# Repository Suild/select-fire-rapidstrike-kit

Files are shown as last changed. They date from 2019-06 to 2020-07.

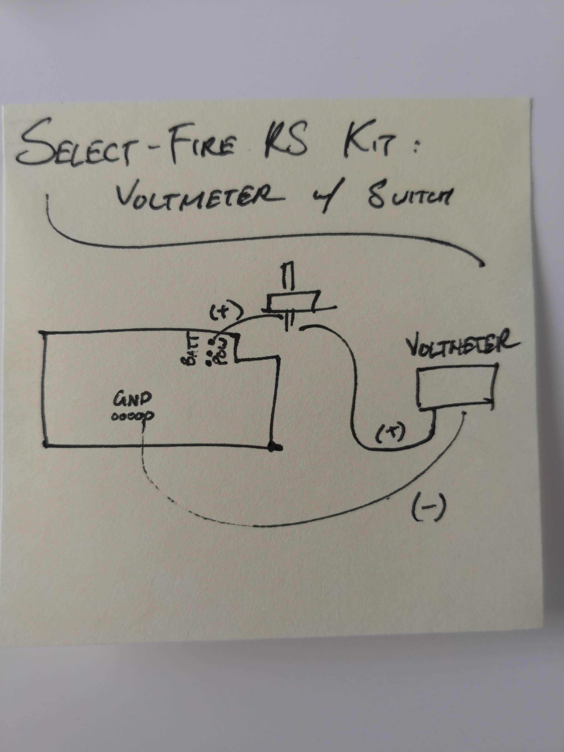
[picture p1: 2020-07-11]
Wiring Diagrams/Voltmeter with Kill Switch.jpg

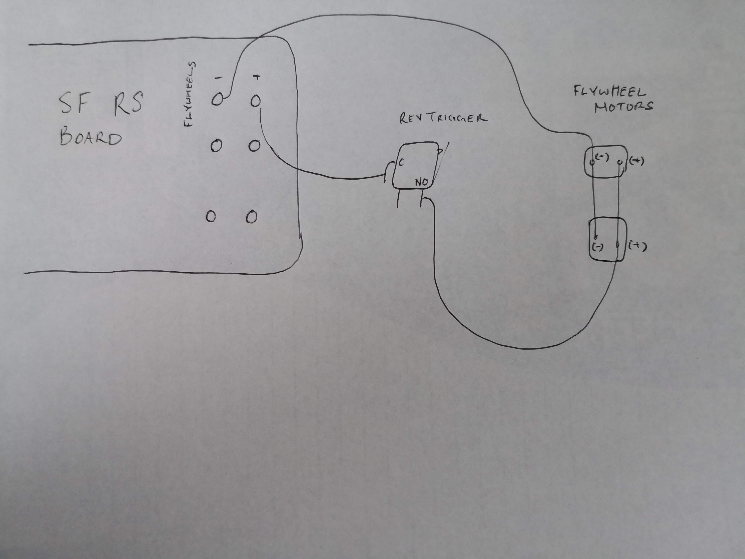
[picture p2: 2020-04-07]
Wiring Diagrams/Flywheel Motors with Microswitch.jpg

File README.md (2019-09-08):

# select-fire-rapidstrike-kit
Schematics, board files, and firmware for every variant of the Select-fire Rapidstrike Kit.



Buy Link: https://suild.com/shop/4

Grants reliable select-fire control to your Rapidstrike with optional rate of fire control using a knob. Like every other kit, this one is super simple to install and requires no soldering directly onto the board to get everything up and runing in under a minute, even easier than a regular RS mod!

Built-in pusher return and solenoid support makes this kit easily adaptable to any custom 3D-printed blaster. A powerful voltage regulator buck converter, on-board Arduino Nano, and breakout of power rails make this ideal for tinkerers and Makers who want to bring this kit one step farther. And everything is open-source.

I hope you find value in this. I personally learned a lot from open-source projects. I've included a PDF for every schematic and images of the top and bottom for every board so you can view them on mobile and without installing Eagle CAD.

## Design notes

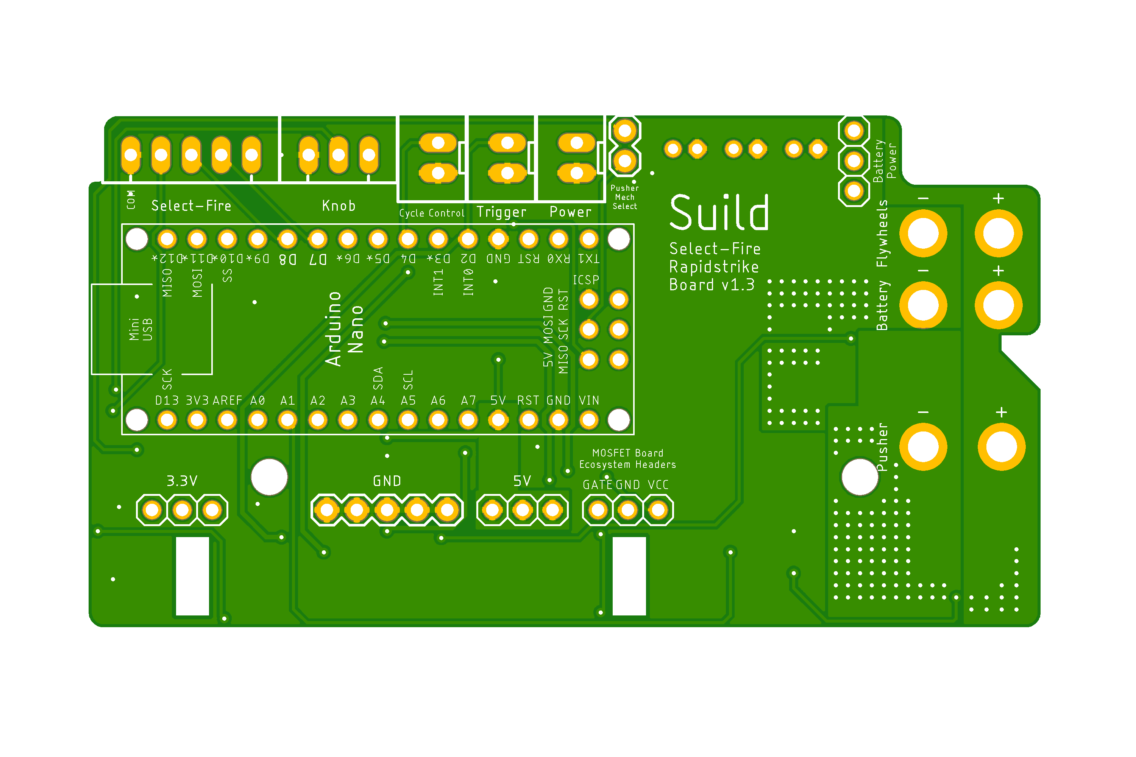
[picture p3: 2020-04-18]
v1.3/Hardware/PCB Top.png

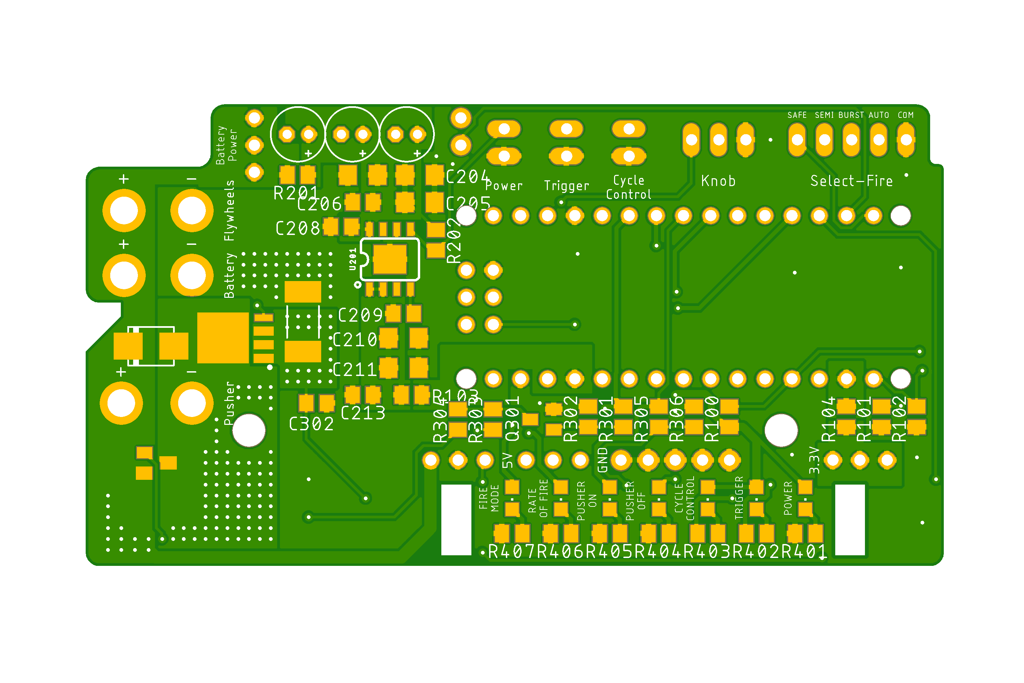
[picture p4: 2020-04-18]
v1.3/Hardware/PCB Bottom.png

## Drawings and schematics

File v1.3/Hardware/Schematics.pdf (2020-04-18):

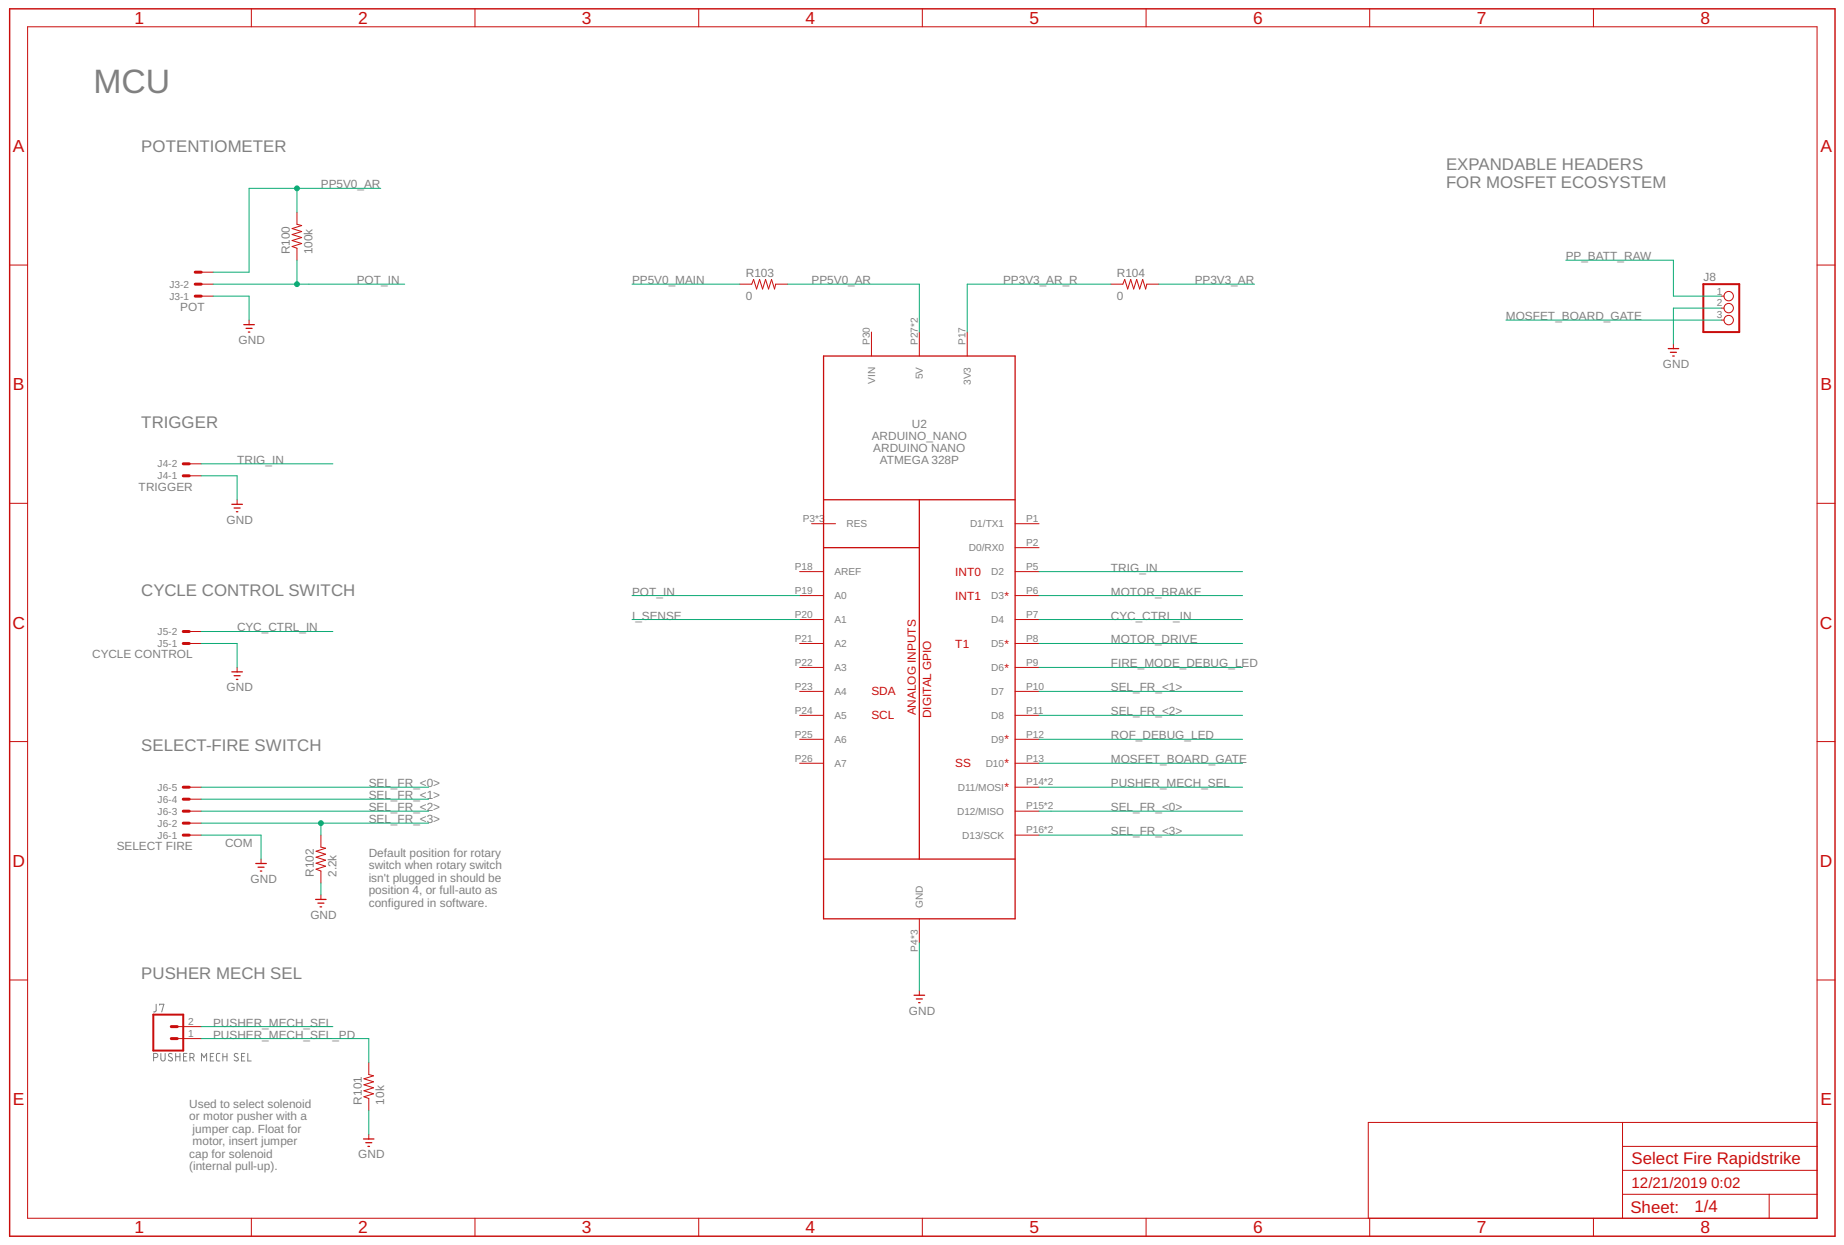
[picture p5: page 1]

ANALOG INPUTS DIGITAL GPIO

Default position for rotary
switch when rotary switch
isn't plugged in should be
position 4, or full-auto as
configured in software.

Used to select solenoid
or motor pusher with a
jumper cap. Float for motor, insert jumper cap for solenoid

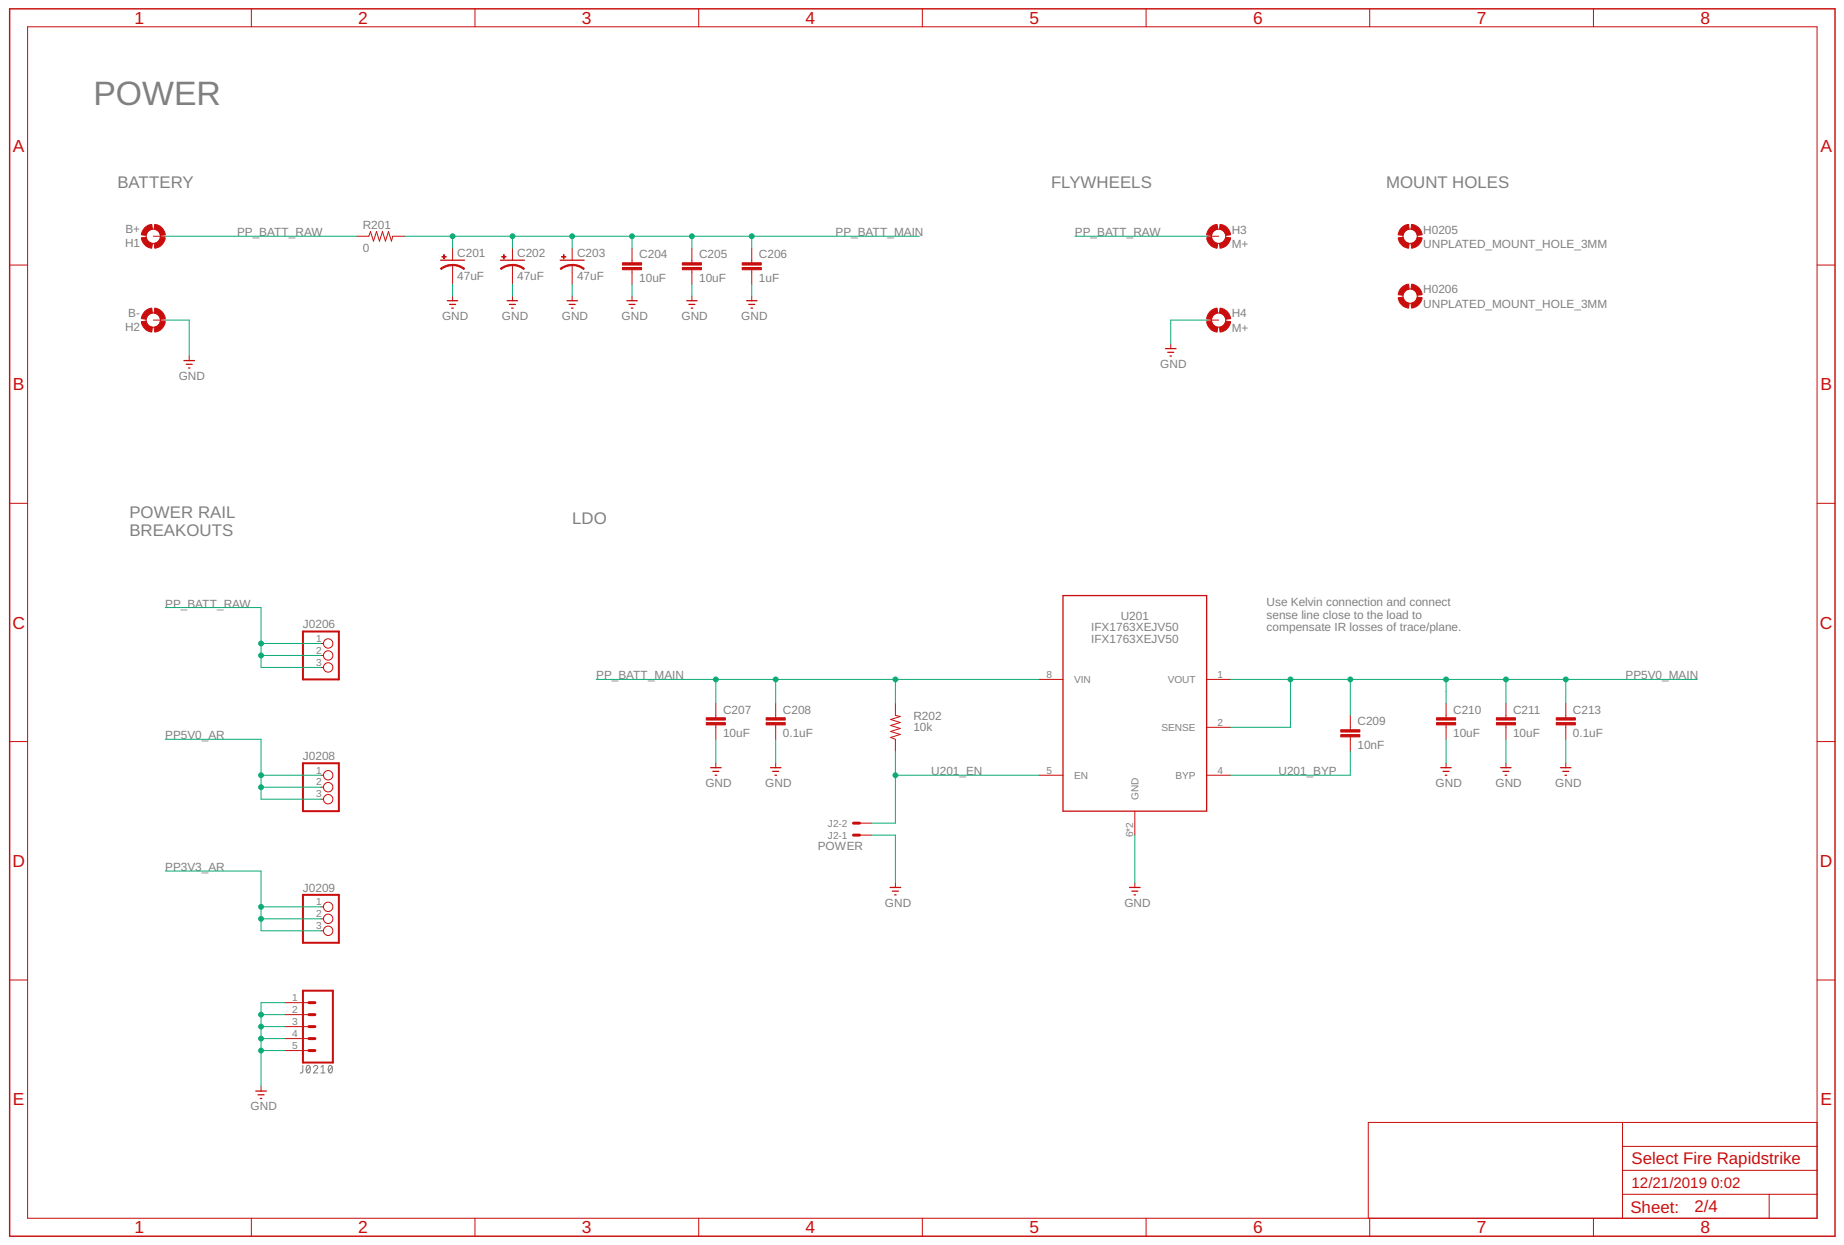
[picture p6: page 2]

Use Kelvin connection and connect sense line close to the load to

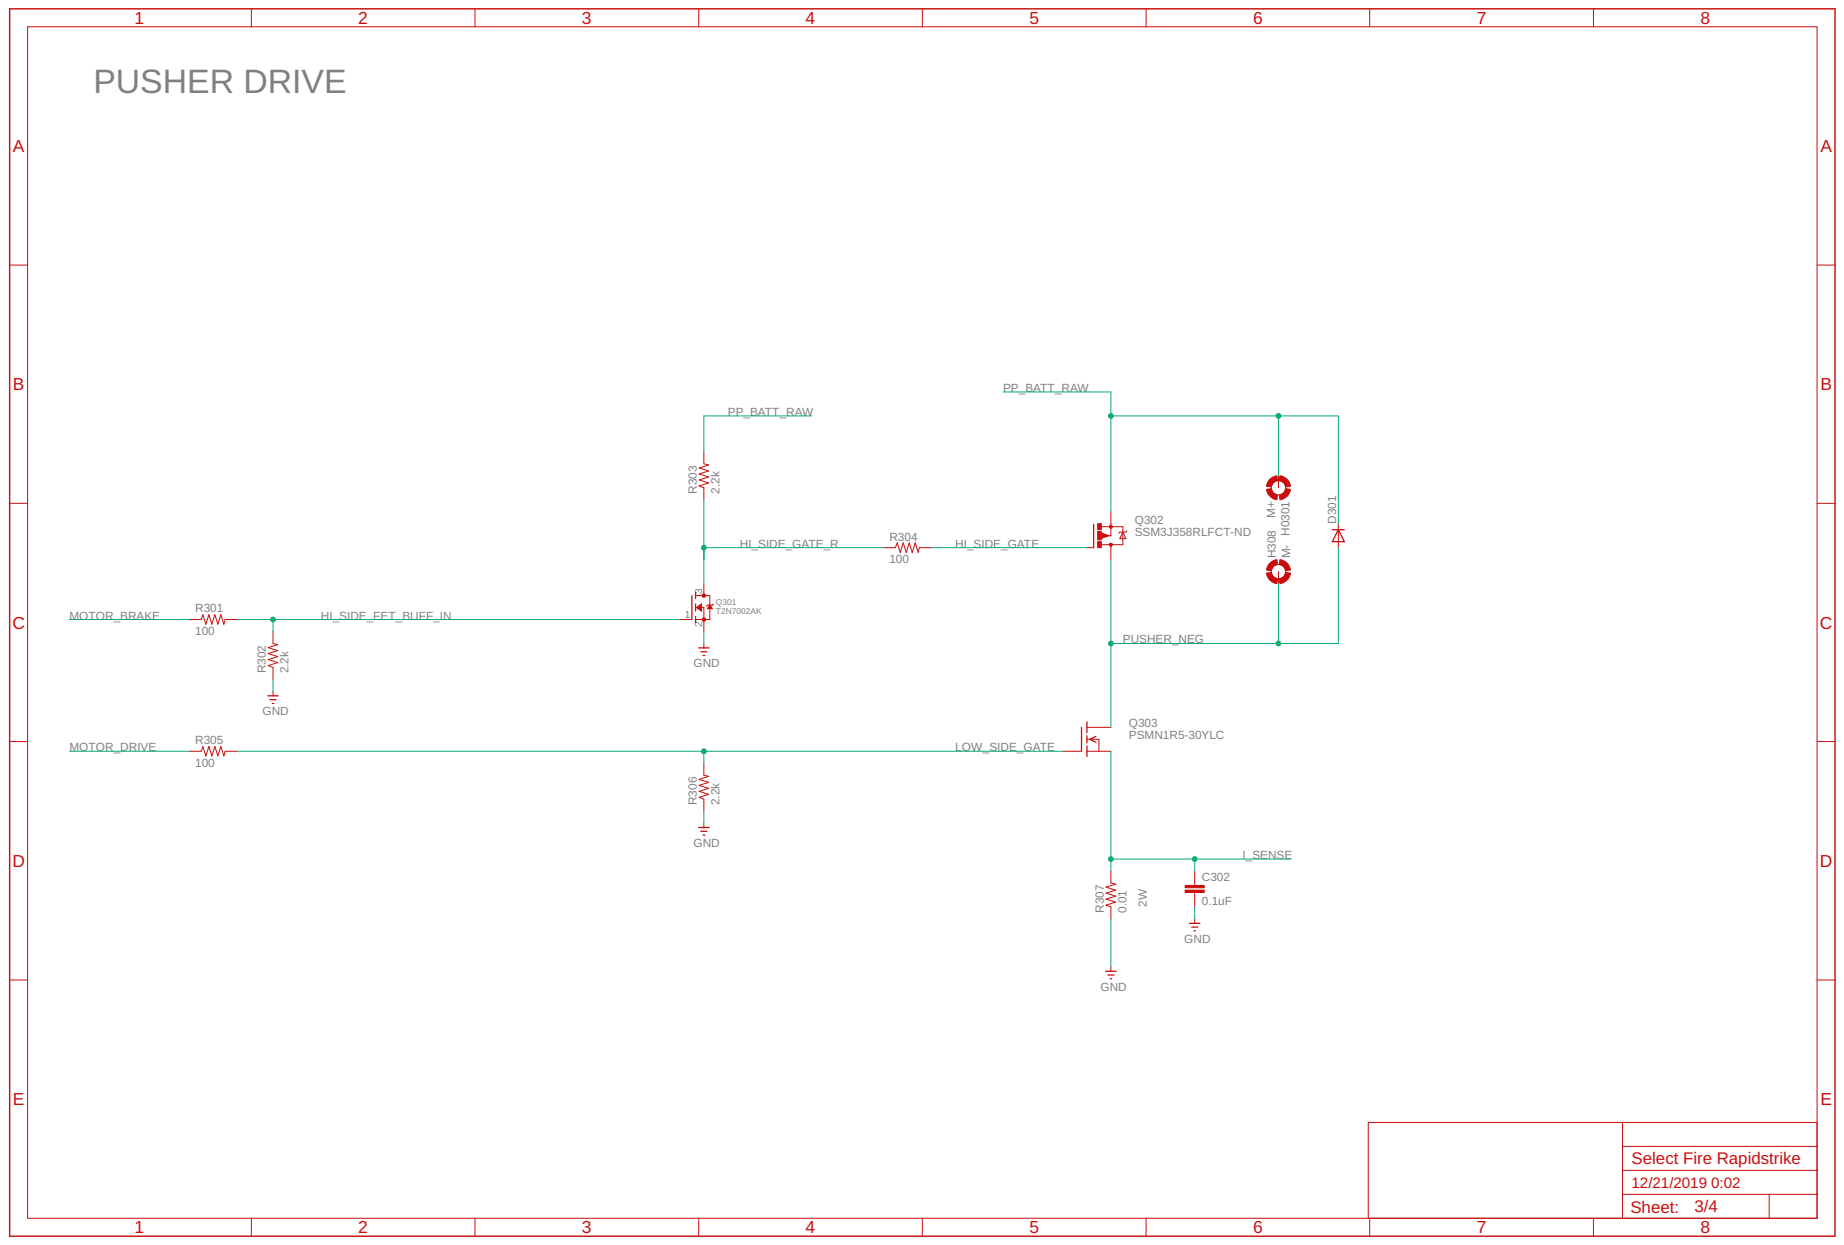
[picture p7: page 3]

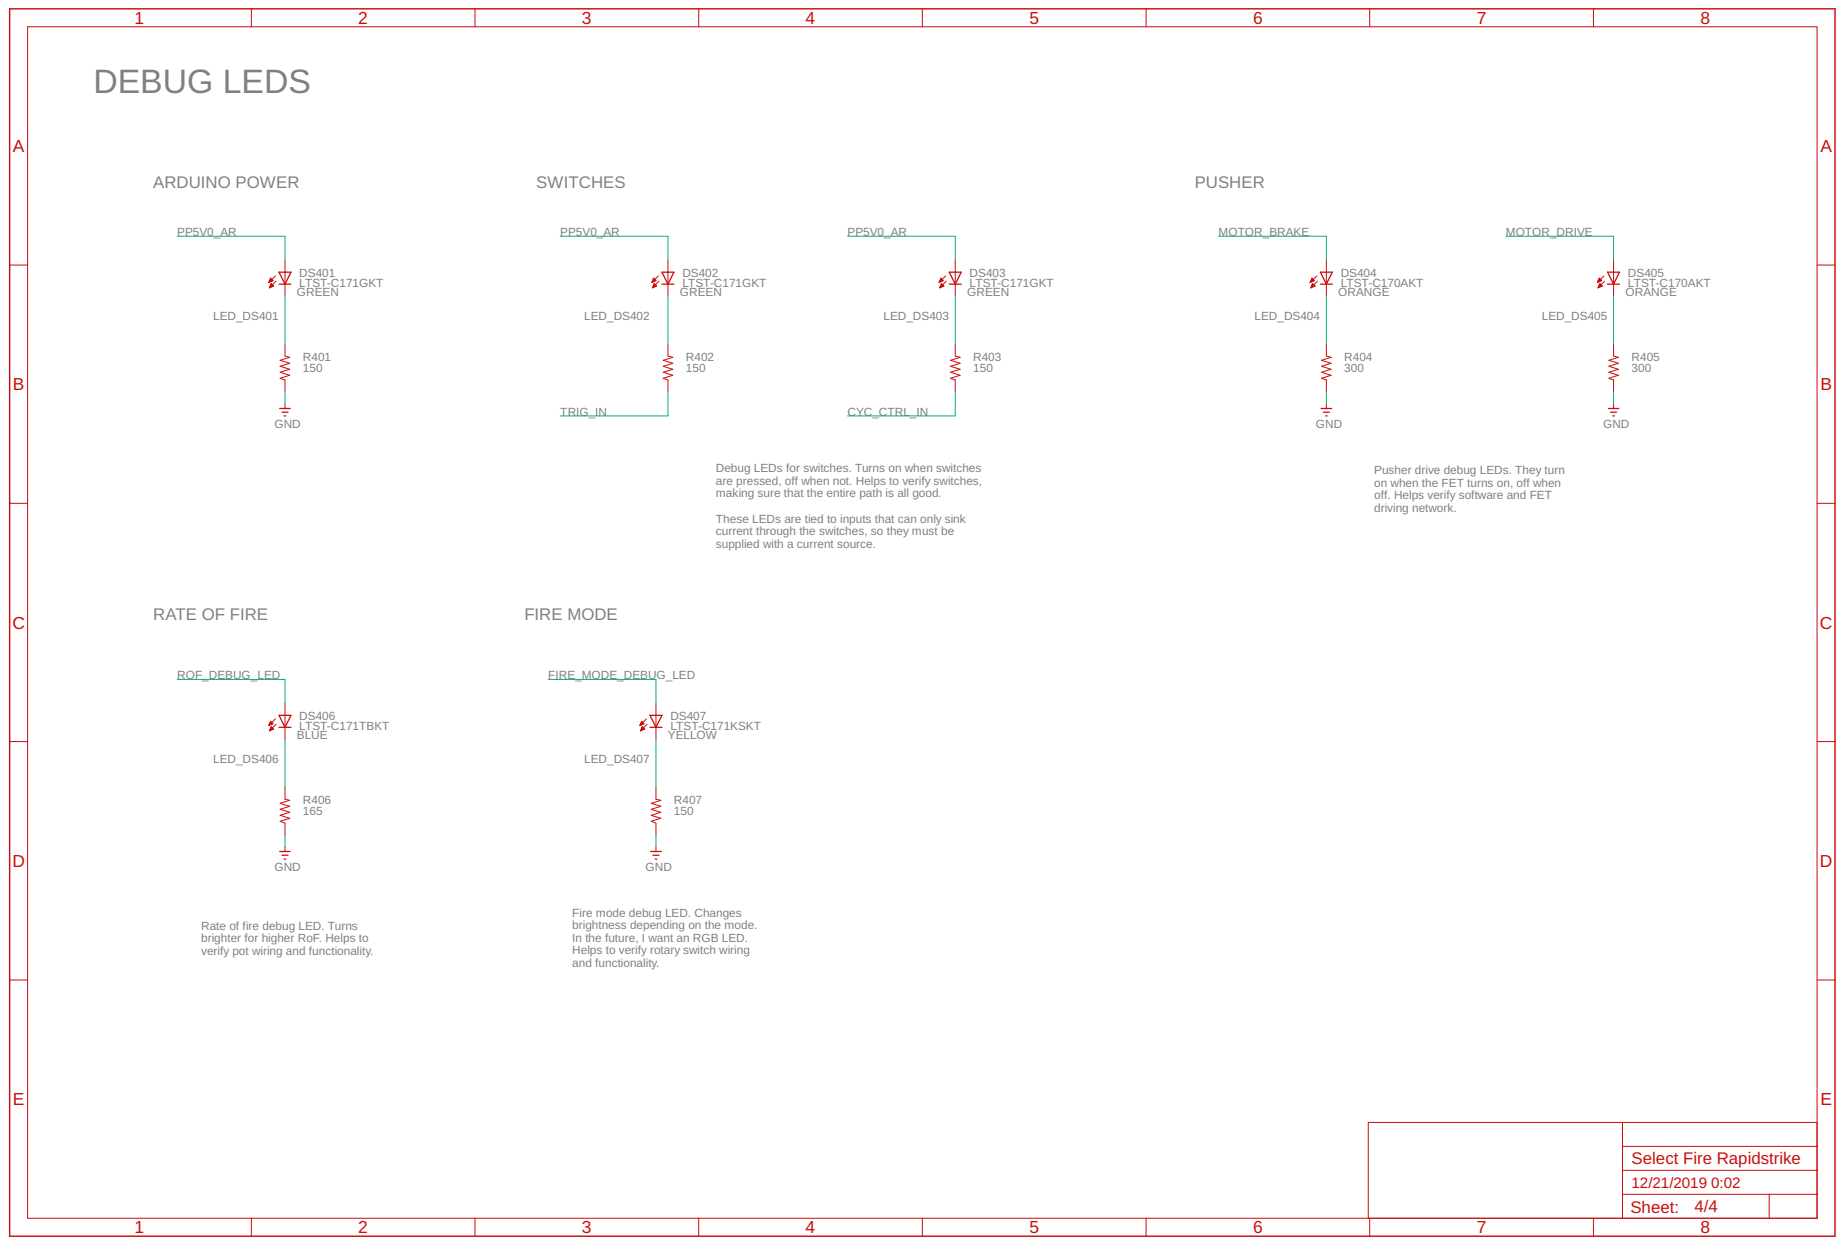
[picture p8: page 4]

Debug LEDs for switches. Turns on when switches are pressed, off when not. Helps to verify switches, making sure that the entire path is all good. These LEDs are tied to inputs that can only sink

Pusher drive debug LEDs. They turn
on when the FET turns on, off when
off. Helps verify software and FET
driving network.

current through the switches, so they must be
supplied with a current source.

Fire mode debug LED. Changes brightness depending on the mode.

Rate of fire debug LED. Turns brighter for higher RoF. Helps to

In the future, I want an RGB LED. Helps to verify rotary switch wiring

verify pot wiring and functionality.

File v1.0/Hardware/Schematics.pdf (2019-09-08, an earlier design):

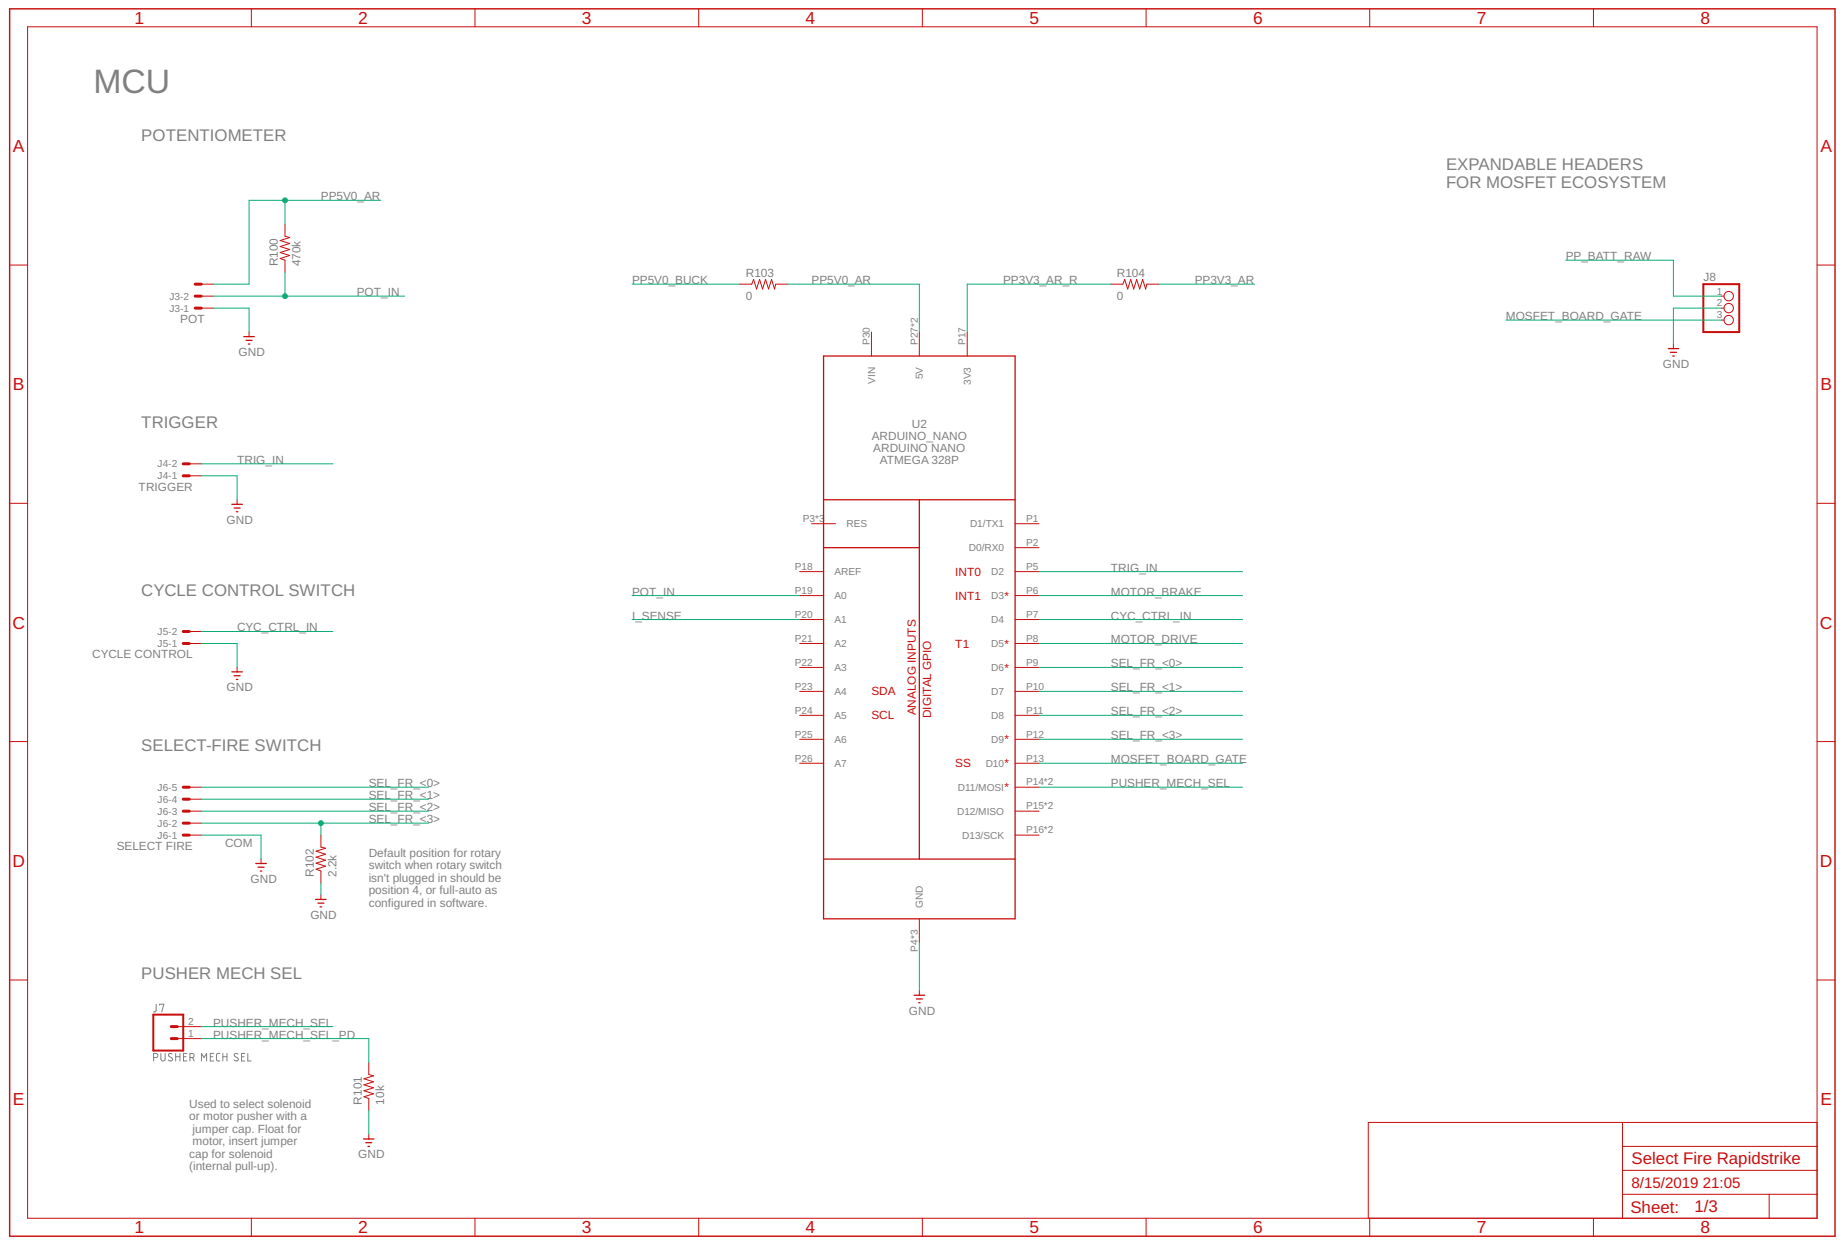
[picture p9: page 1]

ANALOG INPUTS DIGITAL GPIO

Default position for rotary
switch when rotary switch
isn't plugged in should be
position 4, or full-auto as
configured in software.

Used to select solenoid
or motor pusher with a
jumper cap. Float for motor, insert jumper cap for solenoid

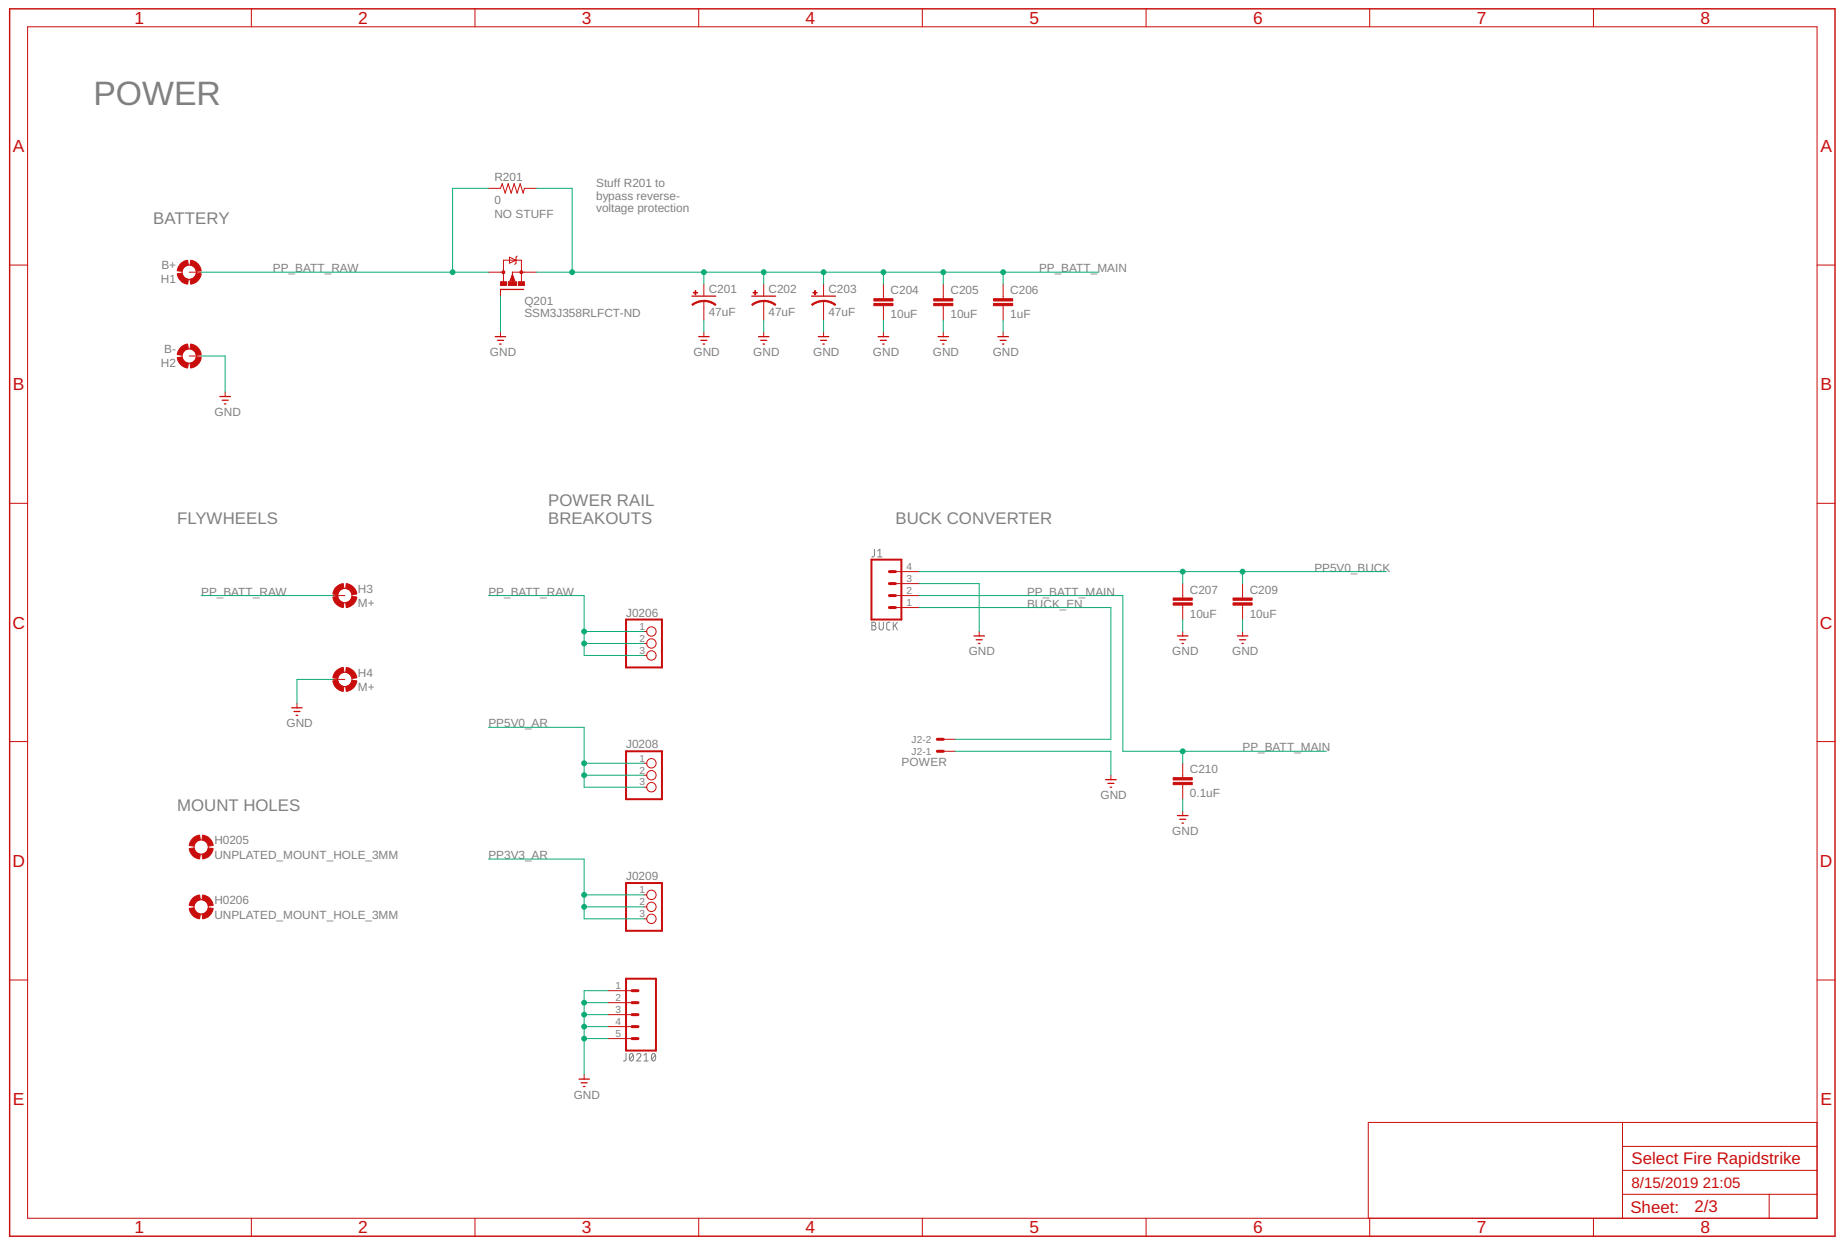
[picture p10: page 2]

Stuff R201 to
bypass reverse- voltage protection

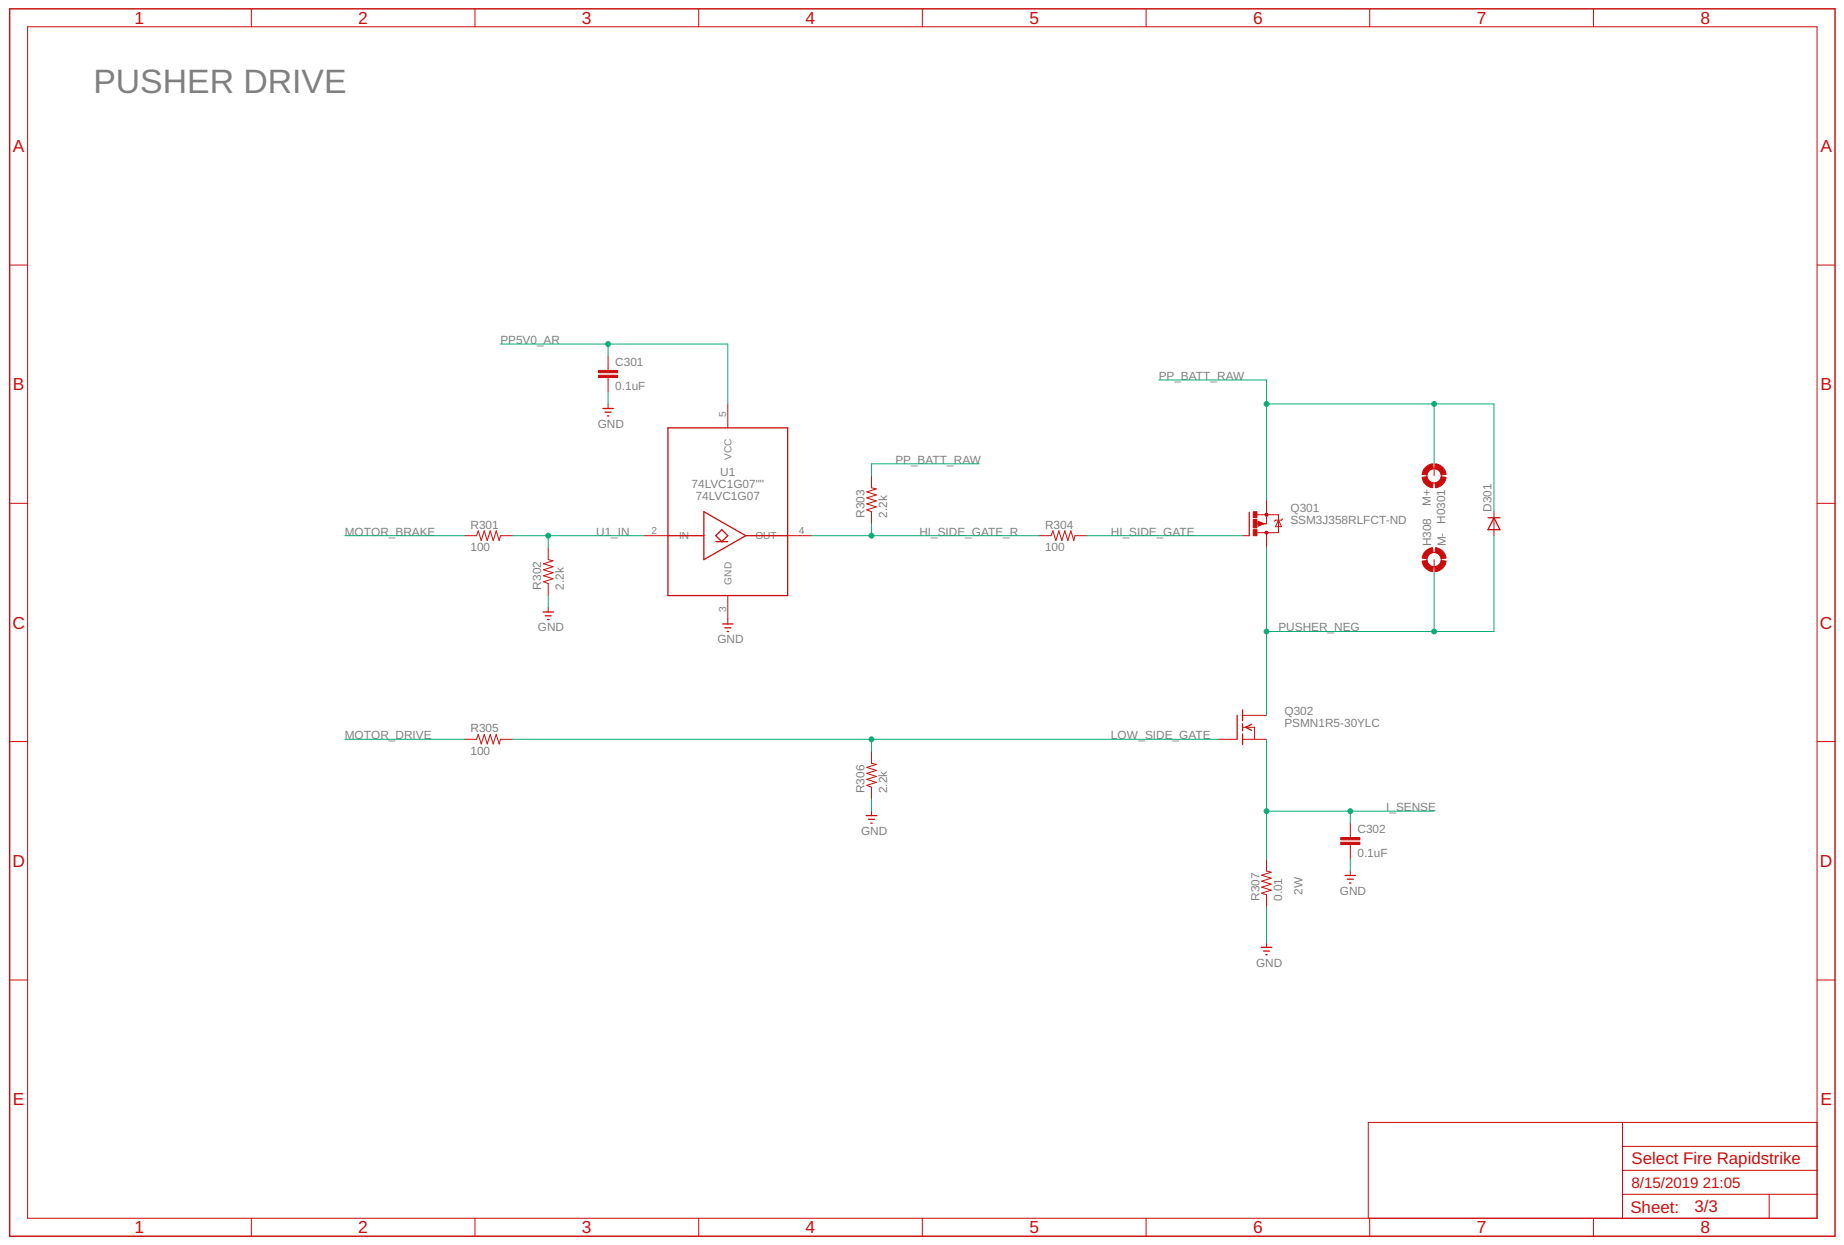
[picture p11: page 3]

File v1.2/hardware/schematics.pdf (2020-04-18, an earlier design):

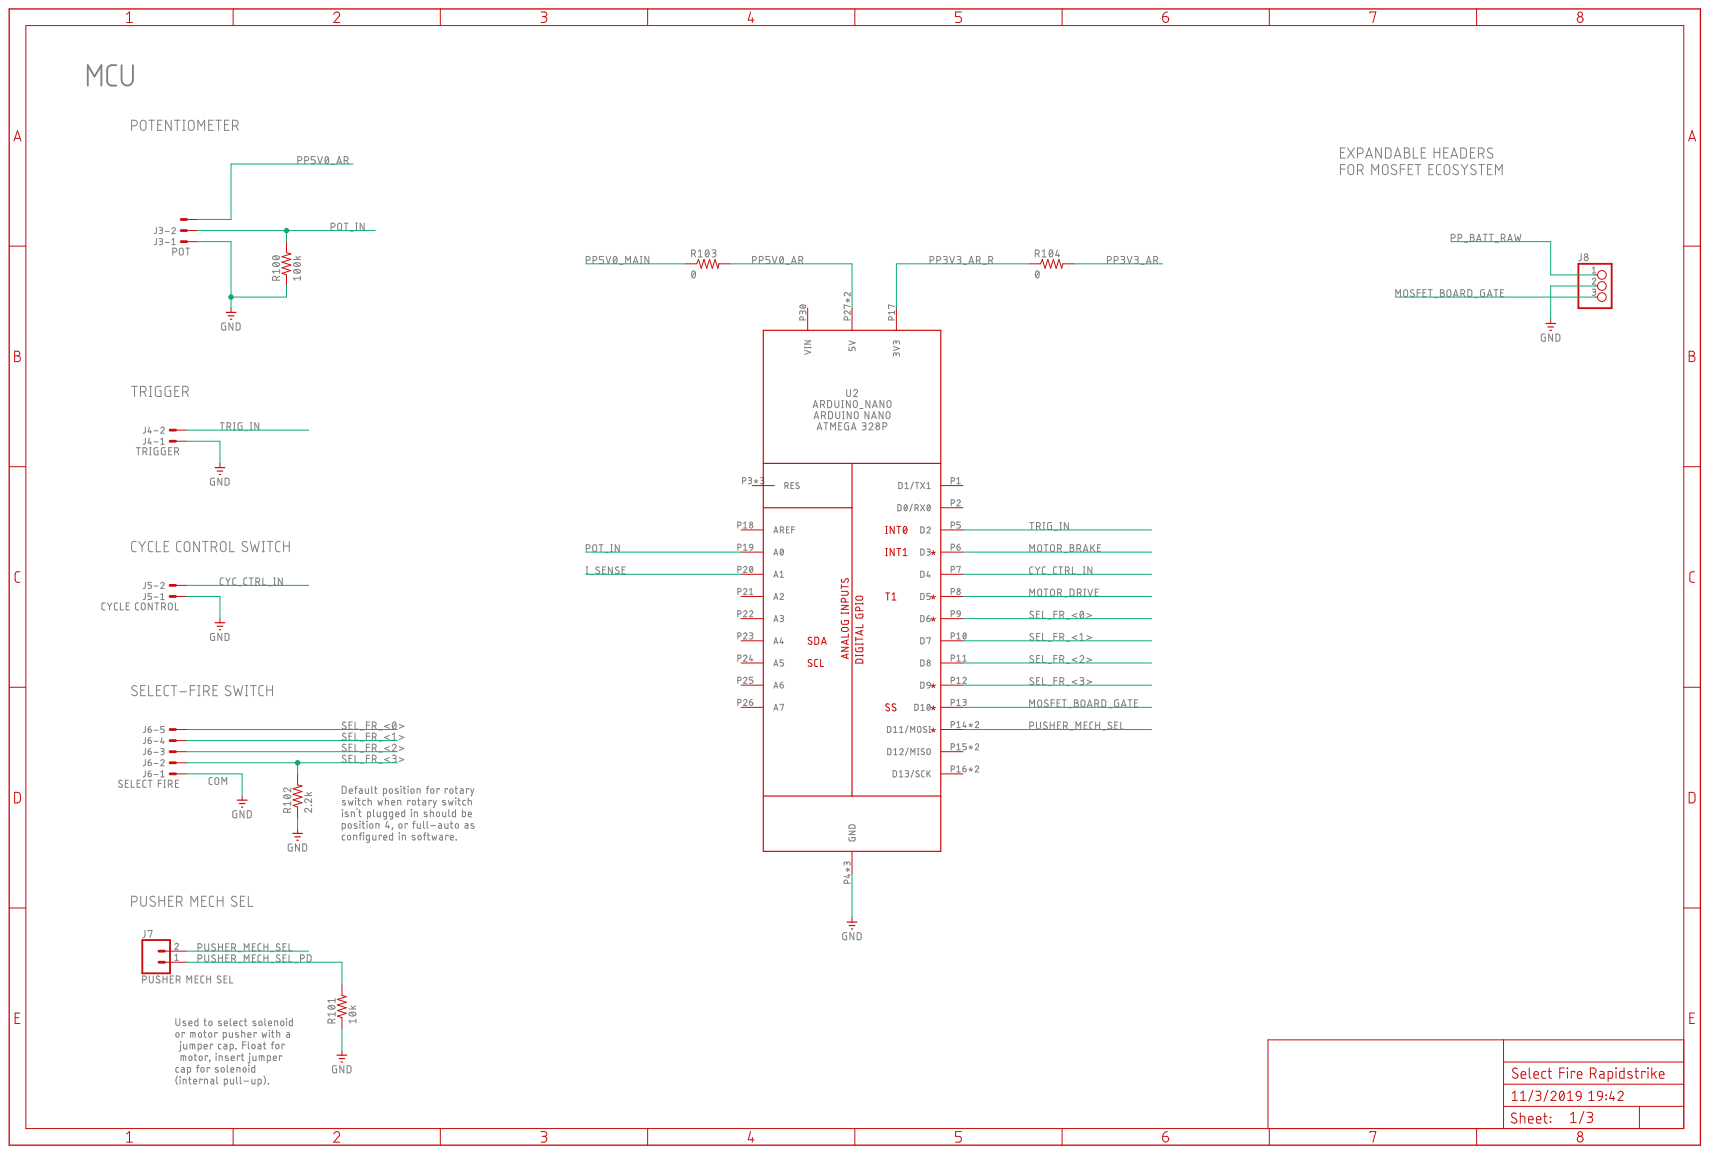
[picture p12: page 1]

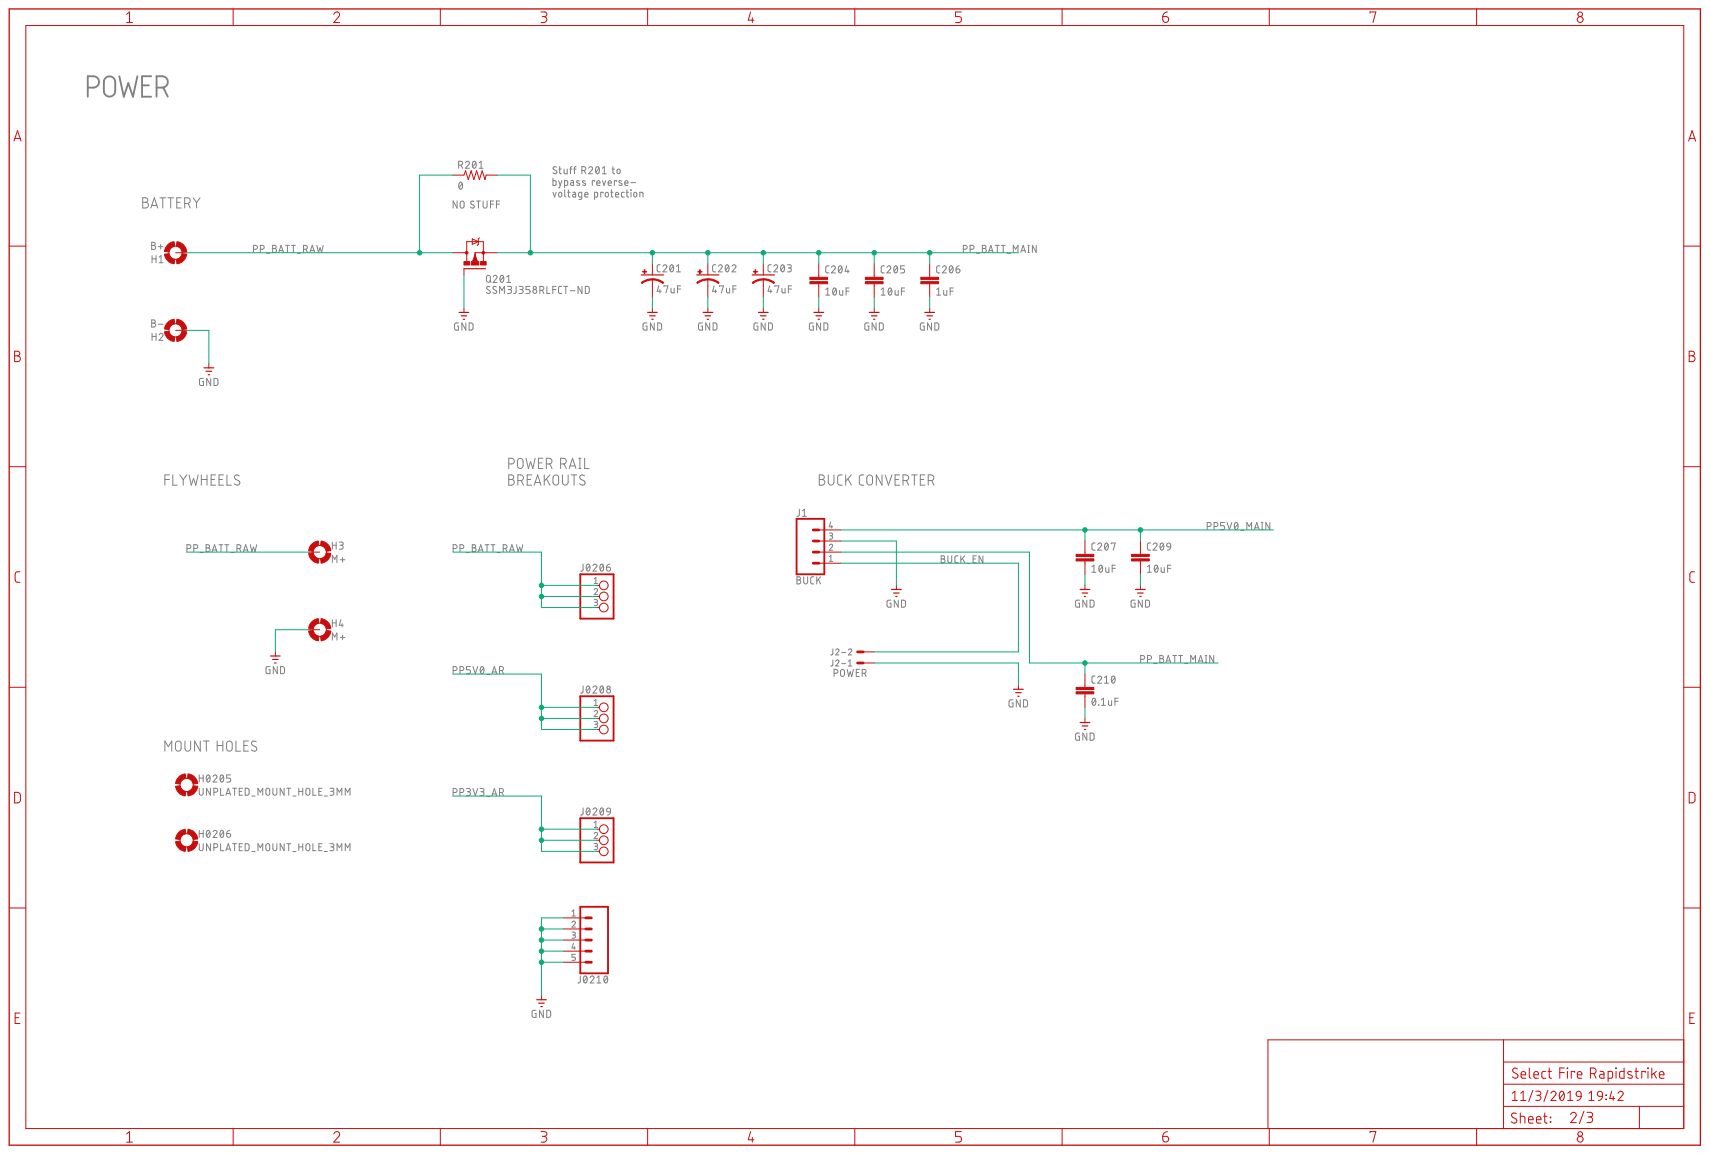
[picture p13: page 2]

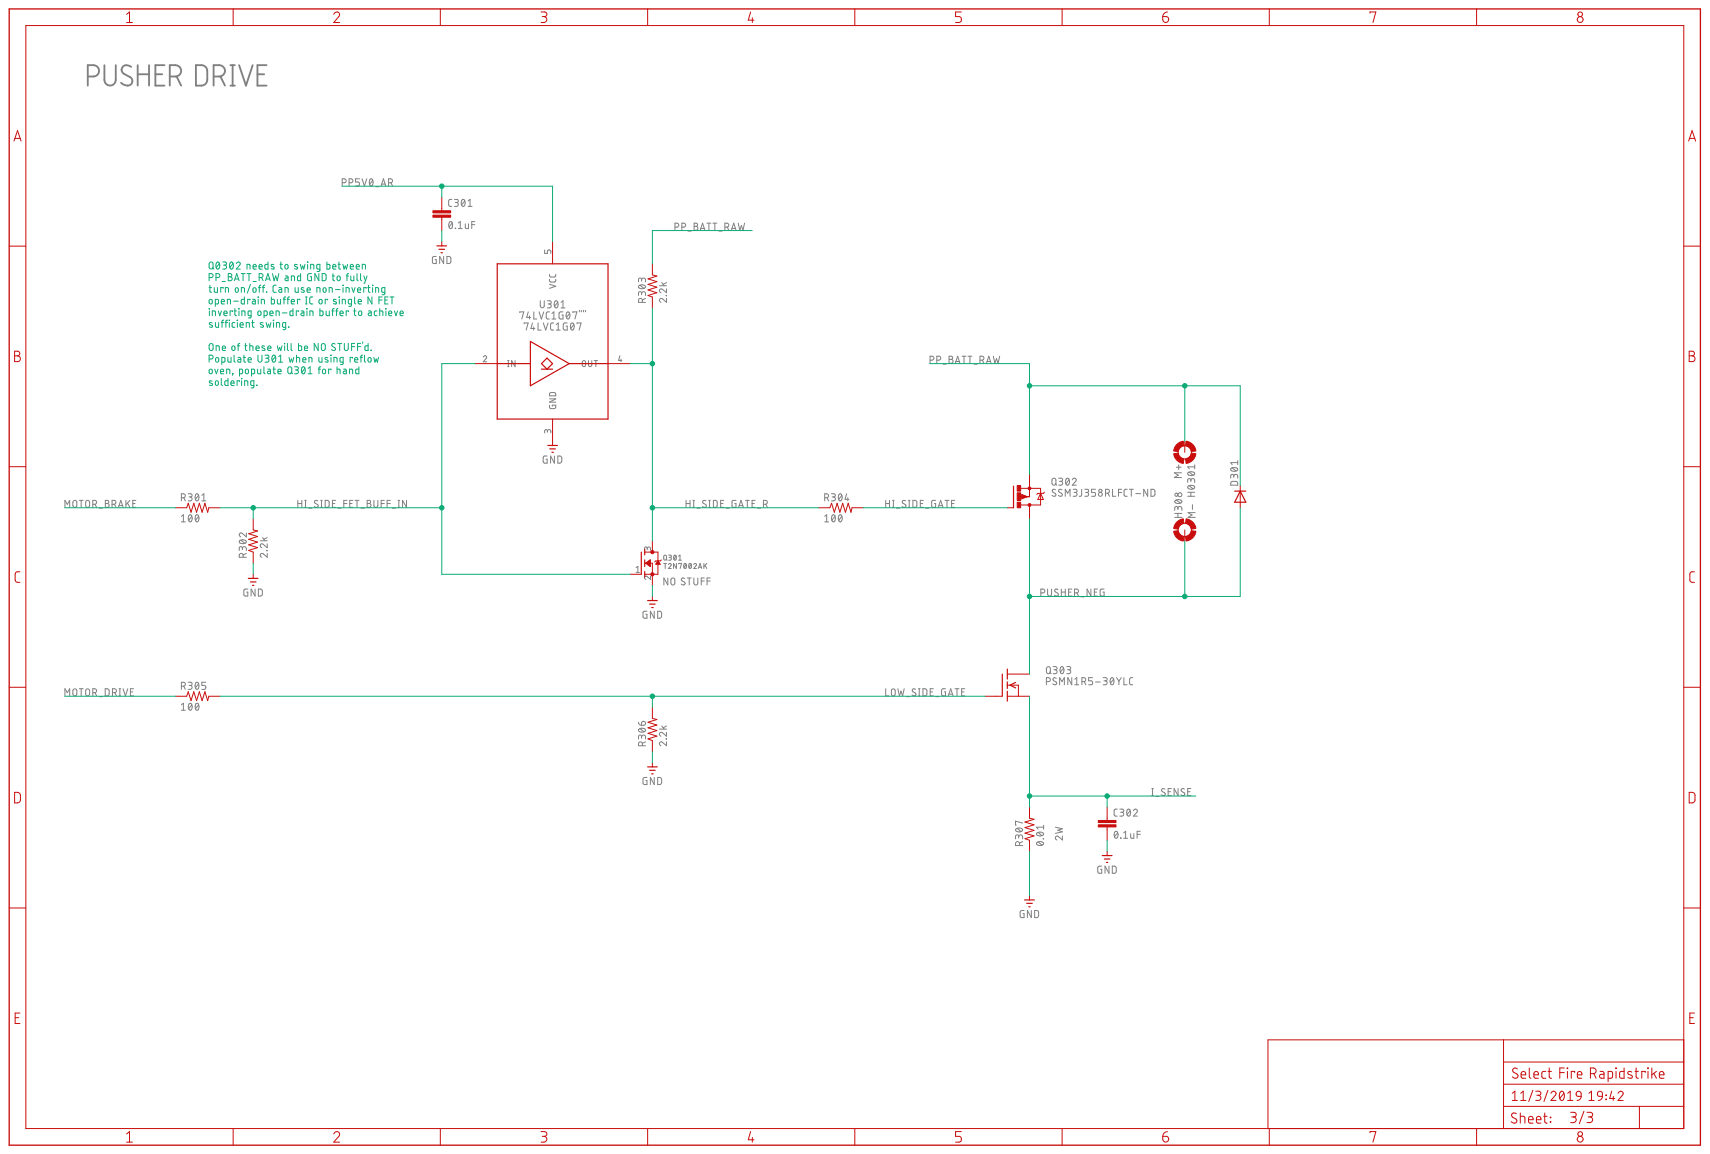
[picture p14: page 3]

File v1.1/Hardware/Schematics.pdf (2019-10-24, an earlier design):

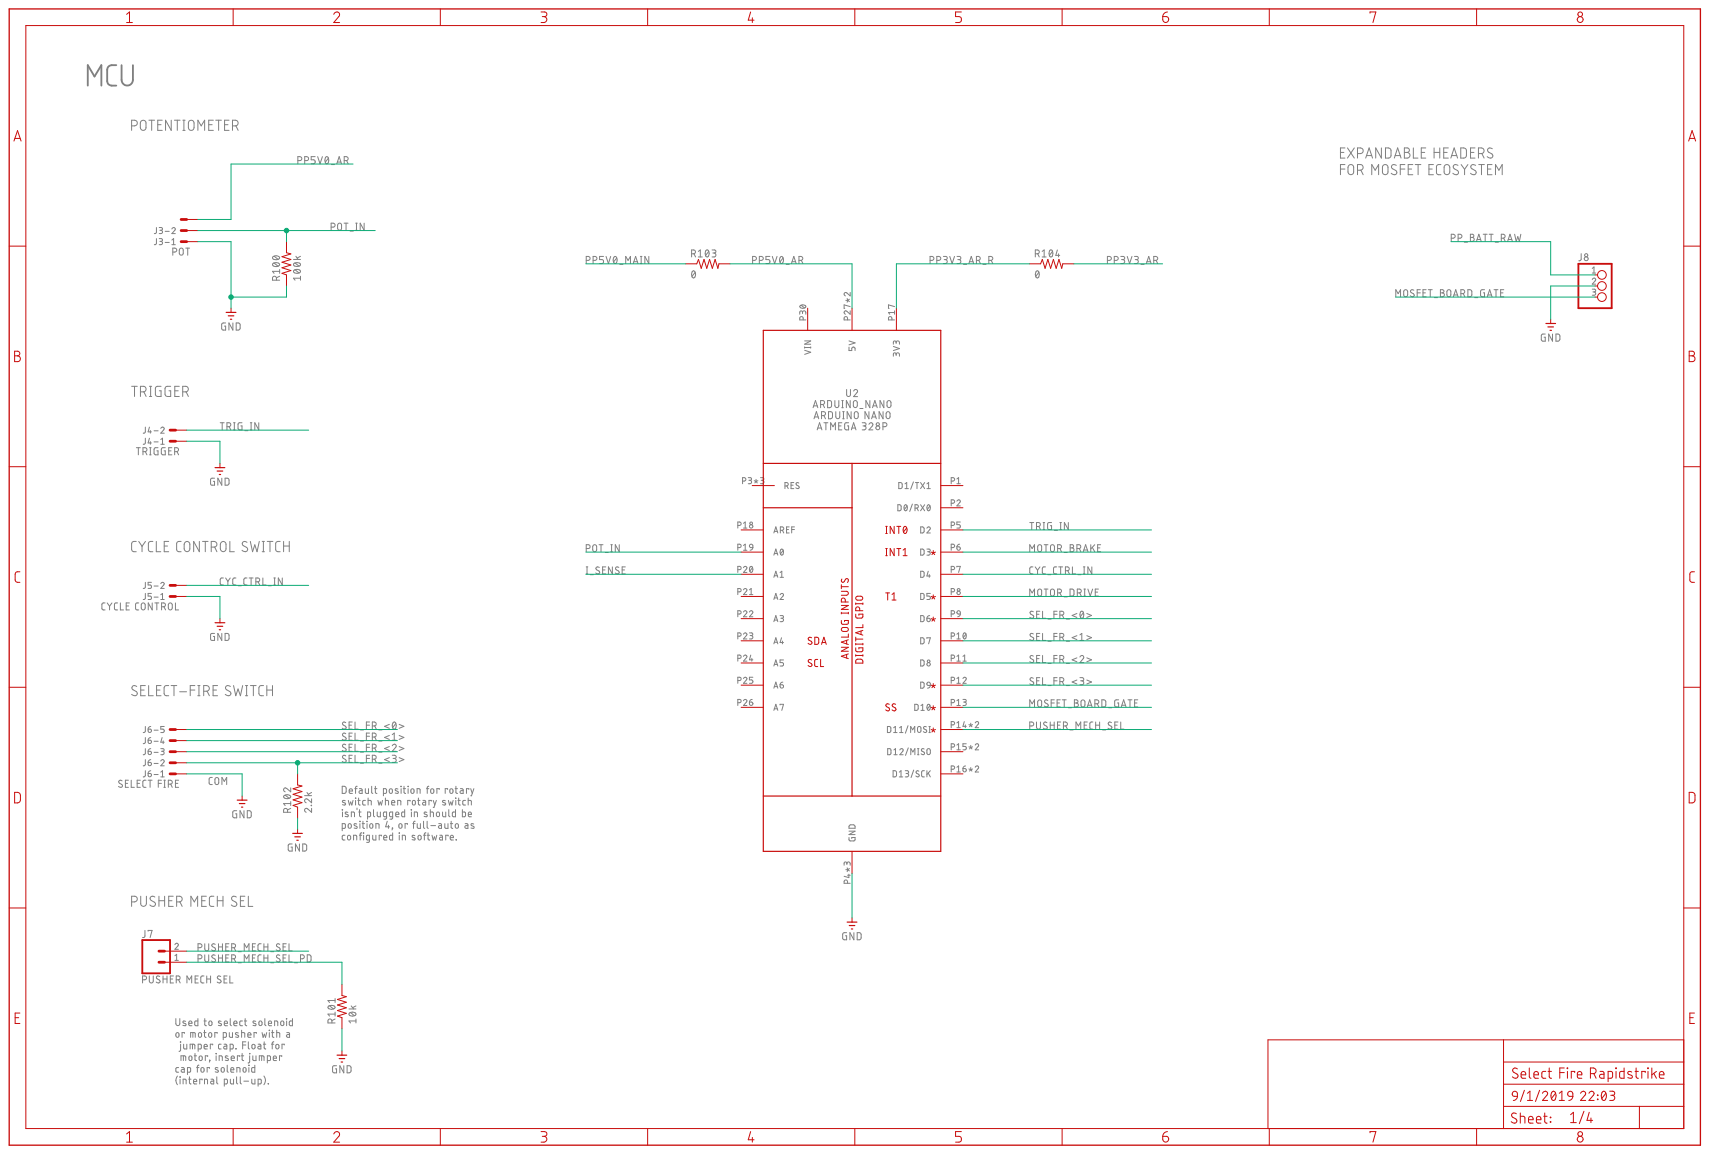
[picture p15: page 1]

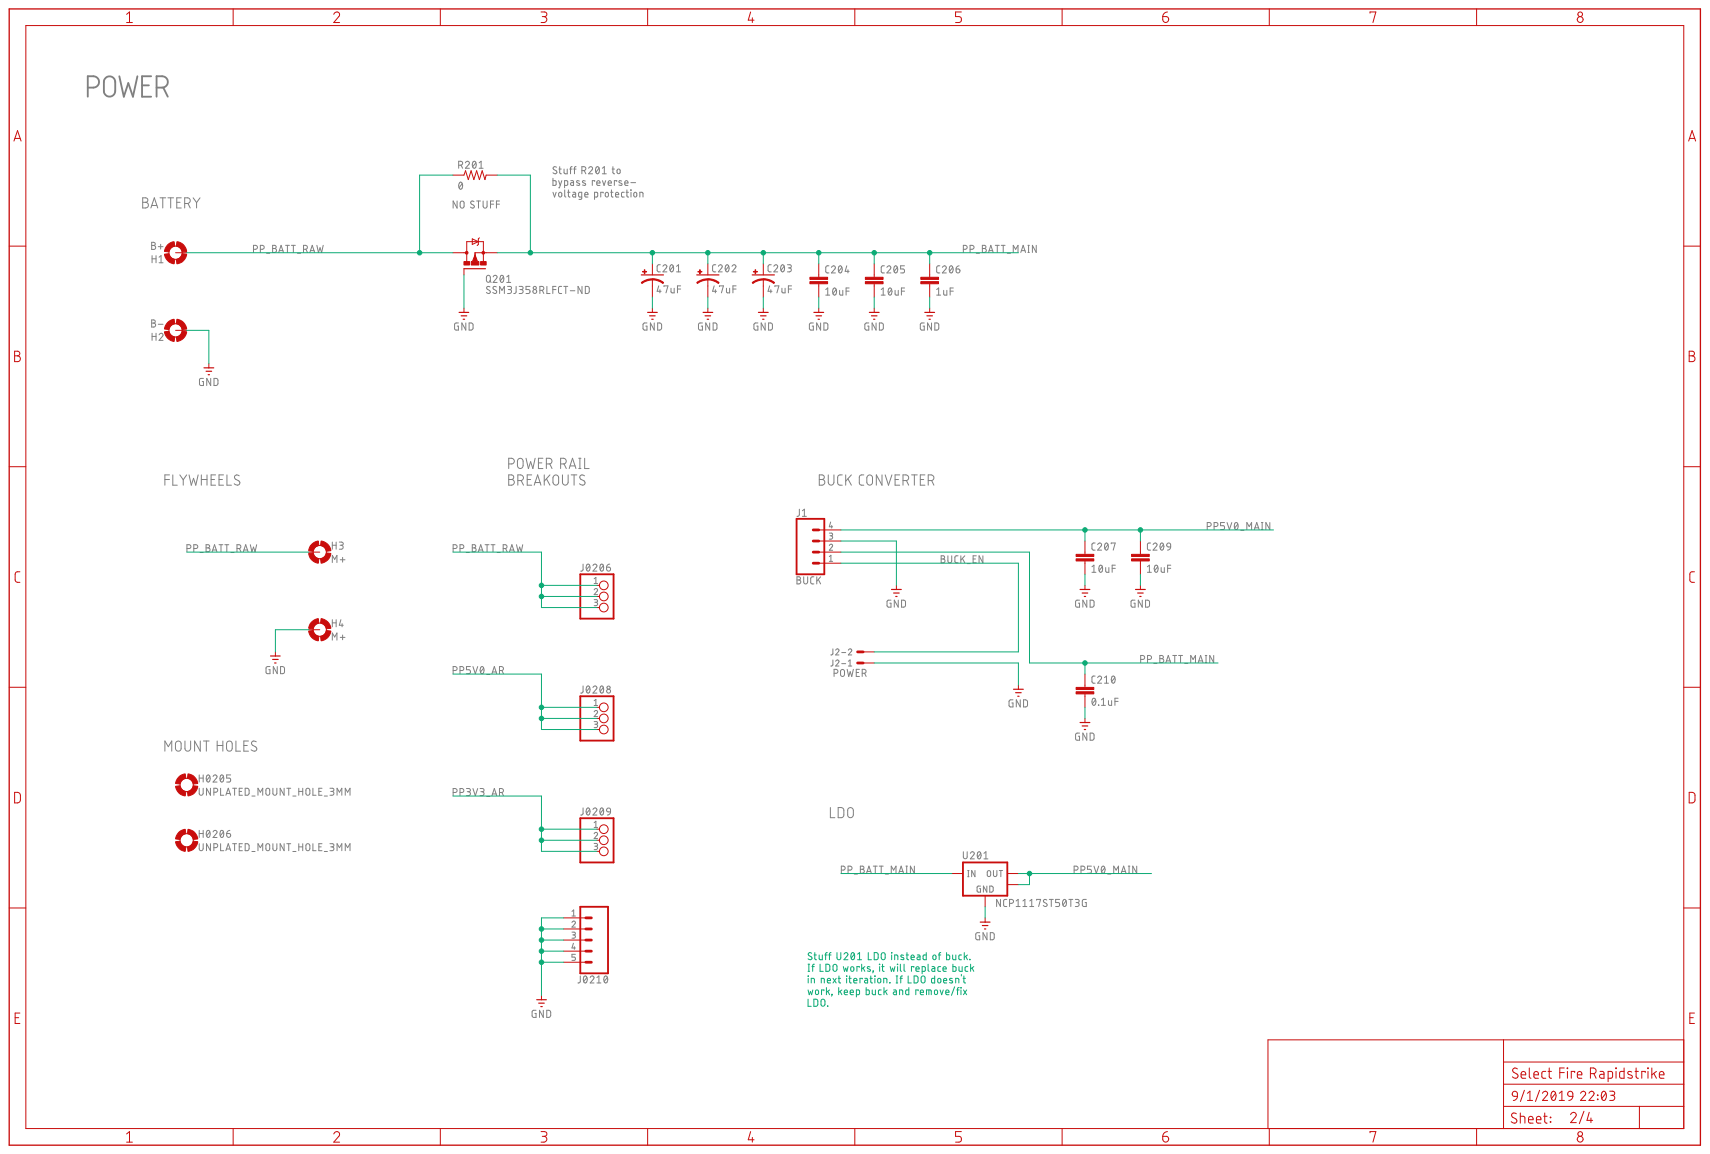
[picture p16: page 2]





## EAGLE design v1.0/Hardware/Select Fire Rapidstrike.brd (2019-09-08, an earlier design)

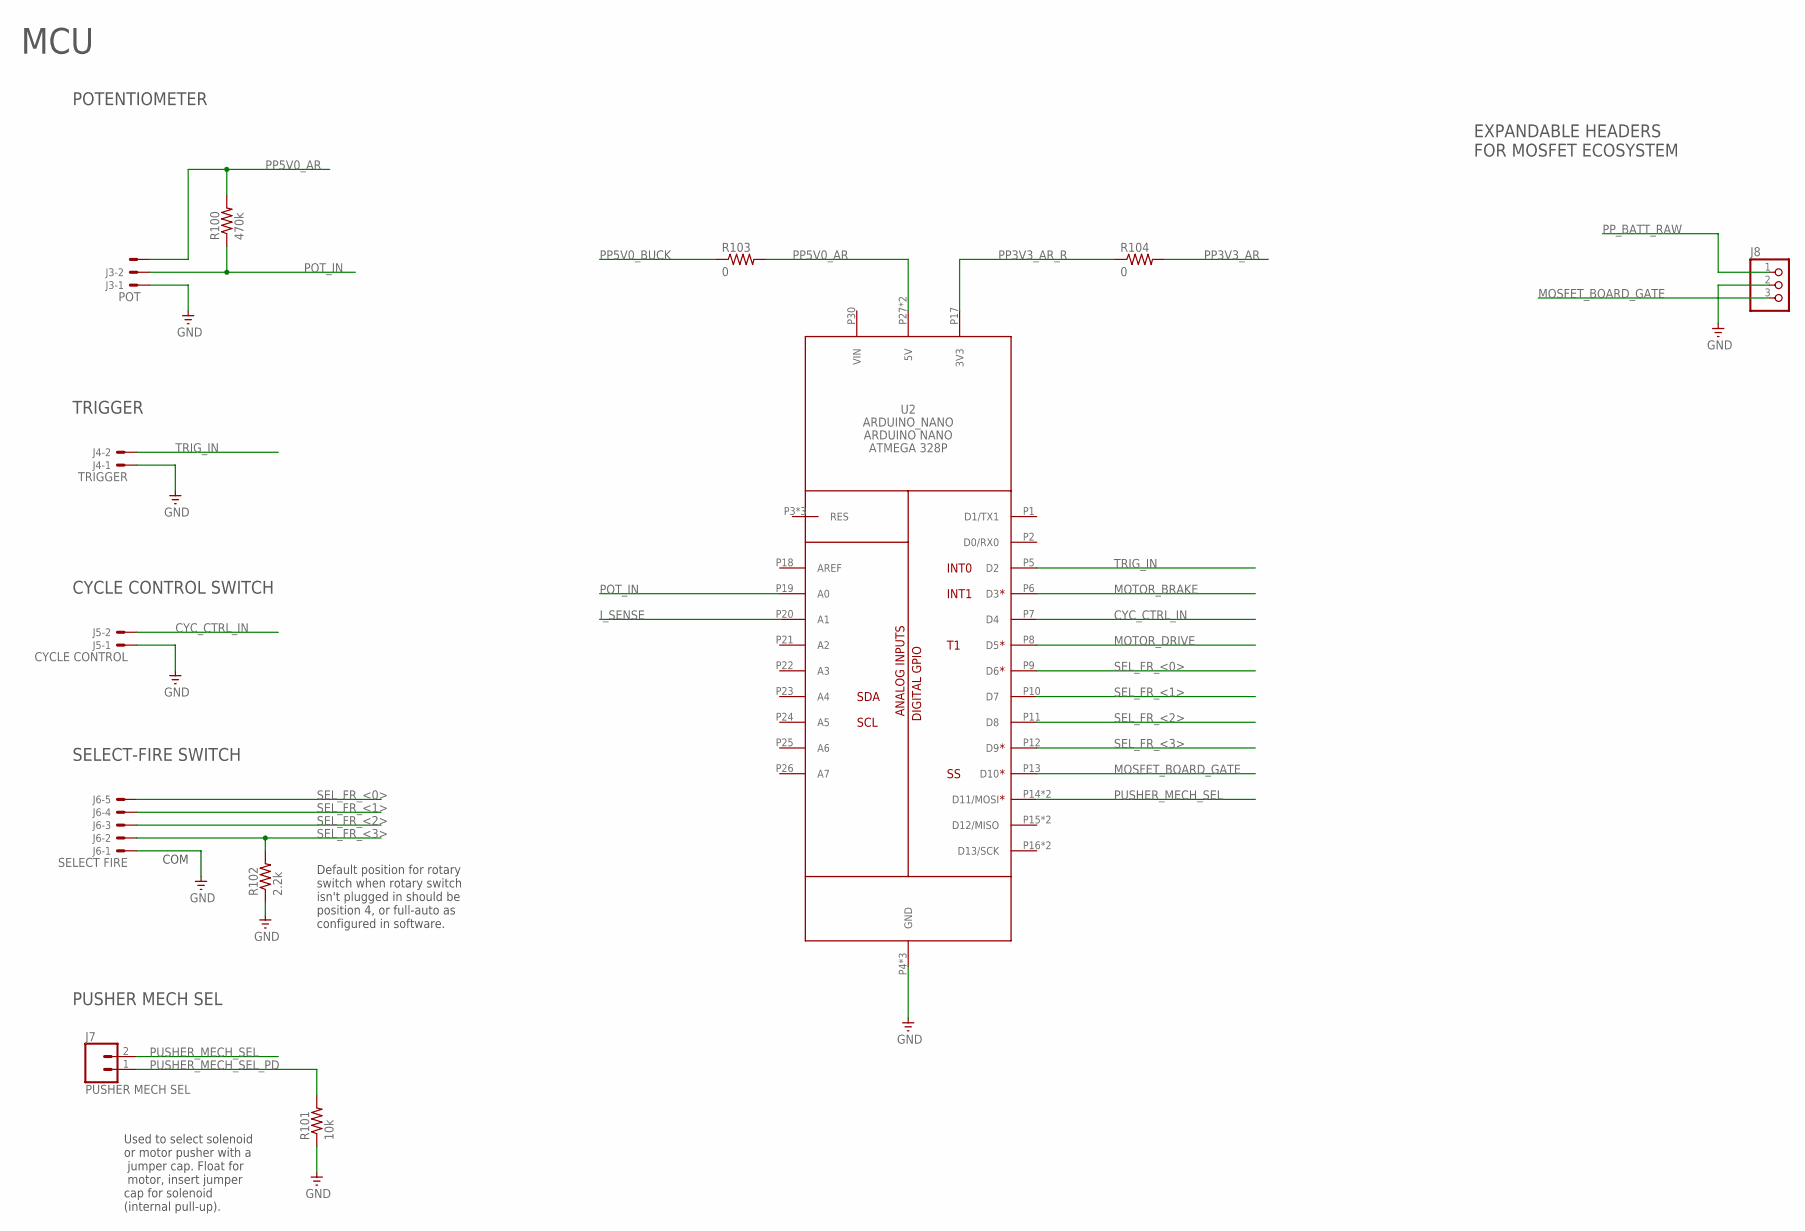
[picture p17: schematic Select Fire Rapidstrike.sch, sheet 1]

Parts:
J3: POT; JST-XH-03-PACKAGE-LONG-PAD
J4: TRIGGER; JST-XH-02-PACKAGE-LONG-PAD
J5: CYCLE CONTROL; JST-XH-02-PACKAGE-LONG-PAD
J6: SELECT FIRE; JST-XH-05-PACKAGE-LONG-PAD
J7: PUSHER MECH SEL; 1X02
J8: PINHD-1X3; 1X03
R100: 470k; M0805
R101: 10k; M0805
R102: 2.2k; M0805
R103, R104: 0; M0805
U2: ARDUINO_NANO

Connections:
CYC_CTRL_IN: J5.2, U2.P7 (D4)
GND: J3.1, J4.1, J5.1, J6.1, J8.2, R101.1, R102.1, U2.P4 (GND), U2.P29 (GND), U2.P32 (GND); also elsewhere on the board
I_SENSE: U2.P20 (A1); also elsewhere on the board
MOSFET_BOARD_GATE: J8.3, U2.P13 (D10)
MOTOR_BRAKE: U2.P6 (D3); also elsewhere on the board
MOTOR_DRIVE: U2.P8 (D5); also elsewhere on the board
POT_IN: J3.2, R100.1, U2.P19 (A0)
PP3V3_AR: R104.2; also elsewhere on the board
PP3V3_AR_R: R104.1, U2.P17 (3V3)
PP5V0_AR: J3.3, R100.2, R103.2, U2.P27 (5V), U2.P36 (5V); also elsewhere on the board
PP5V0_BUCK: R103.1; also elsewhere on the board
PP_BATT_RAW: J8.1; also elsewhere on the board
PUSHER_MECH_SEL: J7.2, U2.P14 (D11/MOSI), U2.P34 (D11/MOSI)
PUSHER_MECH_SEL_PD: J7.1, R101.2
SEL_FR_<0>: J6.5, U2.P9 (D6)
SEL_FR_<1>: J6.4, U2.P10 (D7)
SEL_FR_<2>: J6.3, U2.P11 (D8)
SEL_FR_<3>: J6.2, R102.2, U2.P12 (D9)
TRIG_IN: J4.2, U2.P5 (D2)

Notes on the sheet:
MCU
POTENTIOMETER
TRIGGER
CYCLE CONTROL SWITCH
SELECT-FIRE SWITCH
EXPANDABLE HEADERS FOR MOSFET ECOSYSTEM
PUSHER MECH SEL
Default position for rotary switch when rotary switch isn't plugged in should be position 4, or full-auto as configured in software.
Used to select solenoid or motor pusher with a jumper cap. Float for motor, insert jumper cap for solenoid (internal pull-up).
COM

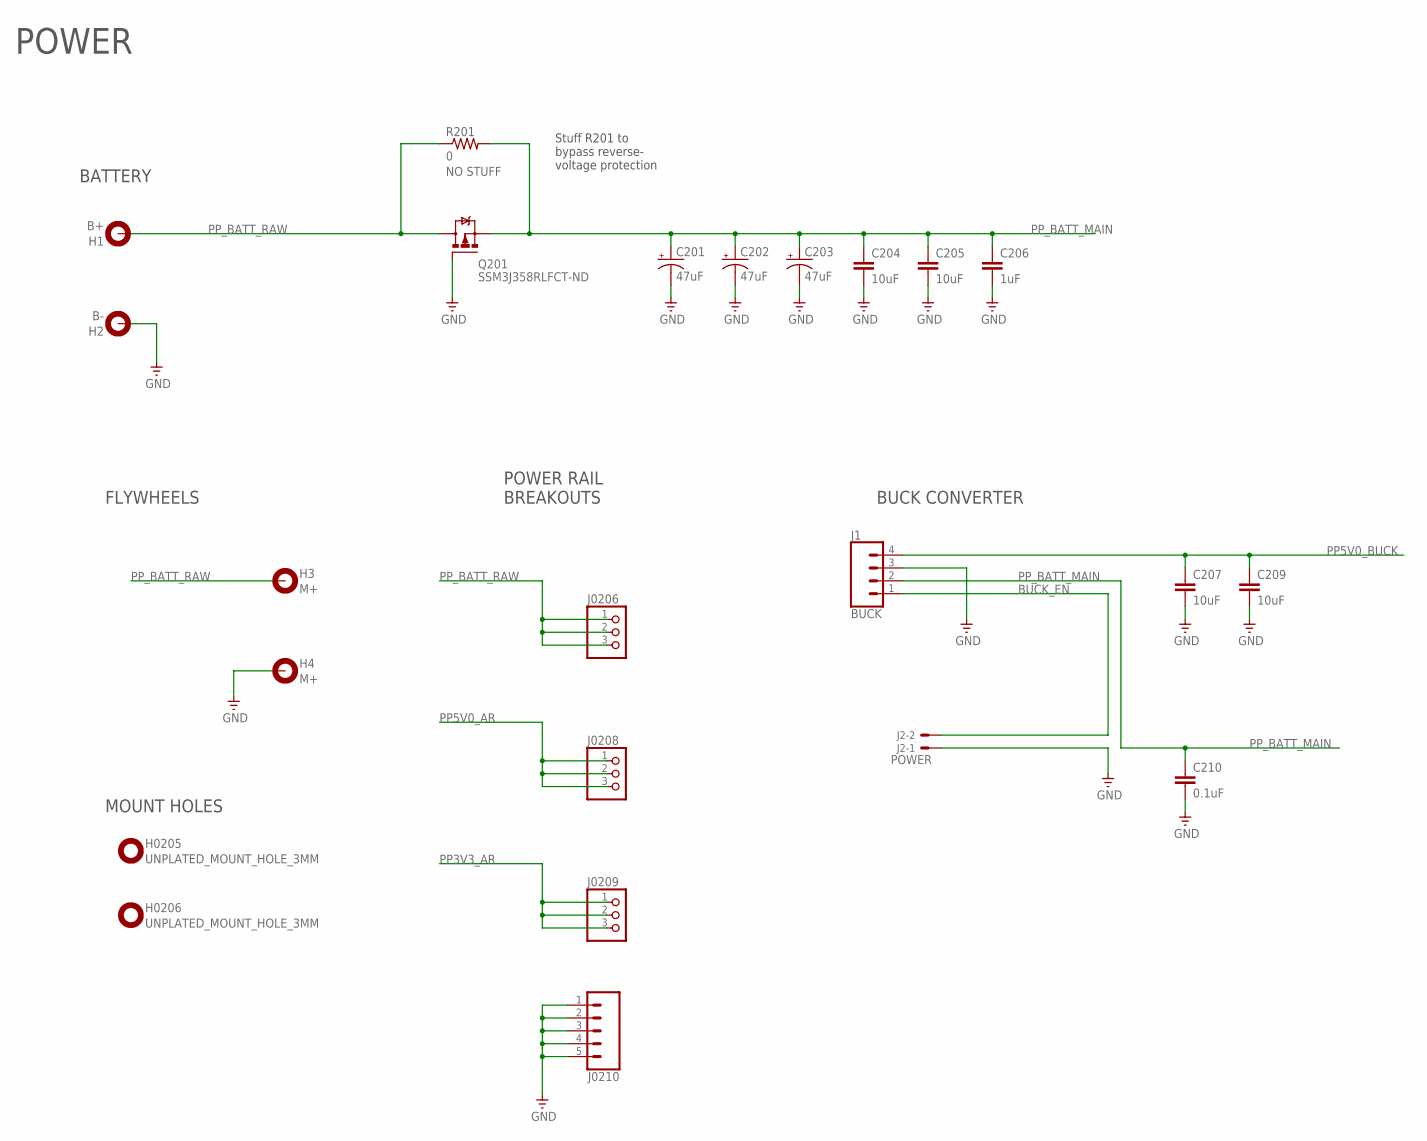
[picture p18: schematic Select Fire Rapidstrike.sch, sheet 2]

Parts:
C201, C202, C203: 47uF; E2-5
C204, C205, C207, C209: 10uF; C1206
C206: 1uF; C0805
C210: 0.1uF; C0805
H1: B+; MOUNT-HOLE-2.5MM
H2: B-; MOUNT-HOLE-2.5MM
H3, H4: M+; MOUNT-HOLE-2.5MM
H0205, H0206: UNPLATED_MOUNT_HOLE_3MM
J1: BUCK; 1X04
J2: POWER; JST-XH-02-PACKAGE-LONG-PAD
J0206, J0208, J0209: PINHD-1X3; 1X03
J0210: CONN_05; 1X05
Q201: SSM3J358RLFCT-ND; SOT-23
R201: 0; R1206

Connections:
BUCK_EN: J1.1, J2.2
GND: C201.-, C202.-, C203.-, C204.2, C205.2, C206.2, C207.2, C209.2, C210.2, H2.P$1, H4.P$1, J1.3, J2.1, J0210.1, J0210.2, J0210.3, J0210.4, J0210.5, Q201.1 (G); also elsewhere on the board
PP3V3_AR: J0209.1, J0209.2, J0209.3; also elsewhere on the board
PP5V0_AR: J0208.1, J0208.2, J0208.3; also elsewhere on the board
PP5V0_BUCK: C207.1, C209.1, J1.4; also elsewhere on the board
PP_BATT_MAIN: C201.+, C202.+, C203.+, C204.1, C205.1, C206.1, C210.1, J1.2, Q201.2 (S), R201.2
PP_BATT_RAW: H1.P$1, H3.P$1, J0206.1, J0206.2, J0206.3, Q201.3 (D), R201.1; also elsewhere on the board

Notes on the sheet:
BUCK CONVERTER
BATTERY
FLYWHEELS
MOUNT HOLES
POWER
POWER RAIL BREAKOUTS
Stuff R201 to bypass reverse- voltage protection

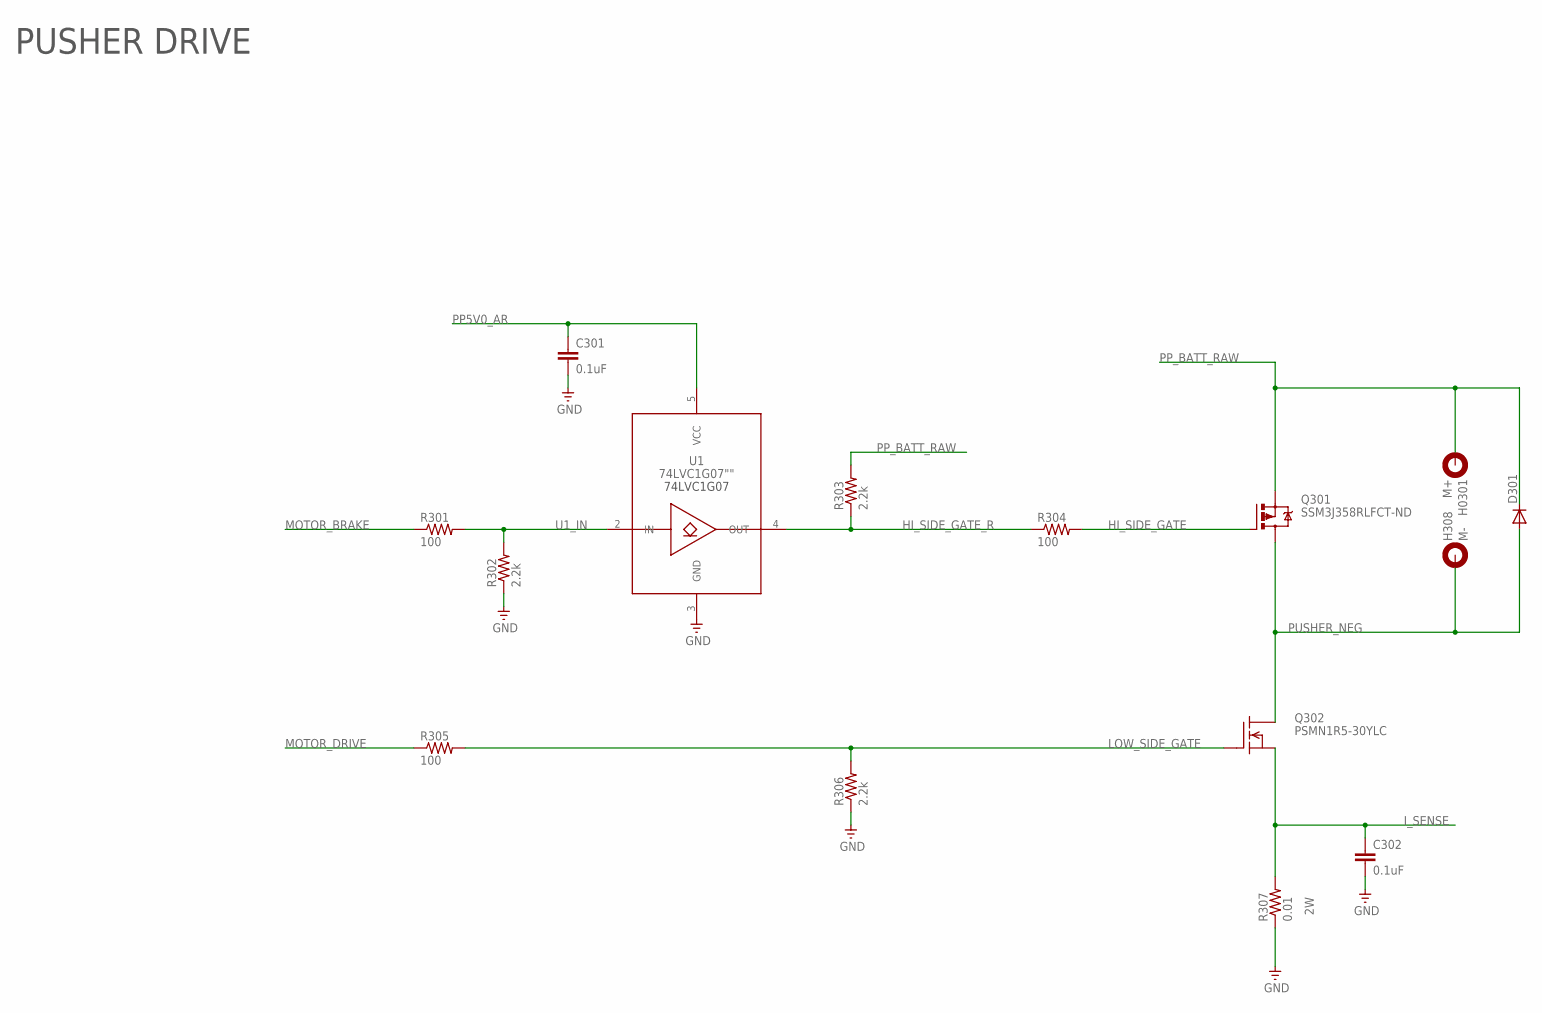
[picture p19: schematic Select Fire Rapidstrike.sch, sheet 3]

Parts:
C301, C302: 0.1uF; C0805
D301: S2A; DO214AA
H0301: M+; MOUNT-HOLE-2.5MM
H308: M-; MOUNT-HOLE-2.5MM
Q301: SSM3J358RLFCT-ND; SOT-23
Q302: PSMN1R5-30YLC; TO127P600X120-5N
R301, R304, R305: 100; M0805
R302, R303, R306: 2.2k; M0805
R307: 0.01; R2512
U1: 74LVC1G07""; SOT353

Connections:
GND: C301.2, C302.2, R302.1, R306.1, R307.1, U1.3 (GND); also elsewhere on the board
HI_SIDE_GATE: Q301.1 (G), R304.2
HI_SIDE_GATE_R: R303.1, R304.1, U1.4 (OUT)
I_SENSE: C302.1, Q302.1 (S), Q302.2 (S), Q302.3 (S), R307.2; also elsewhere on the board
LOW_SIDE_GATE: Q302.4 (G), R305.2, R306.2
MOTOR_BRAKE: R301.1; also elsewhere on the board
MOTOR_DRIVE: R305.1; also elsewhere on the board
PP5V0_AR: C301.1, U1.5 (VCC); also elsewhere on the board
PP_BATT_RAW: D301.C, H0301.P$1, Q301.2 (S), R303.2; also elsewhere on the board
PUSHER_NEG: D301.A, H308.P$1, Q301.3 (D), Q302.5 (D)
U1_IN: R301.2, R302.2, U1.2 (IN)

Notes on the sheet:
PUSHER DRIVE

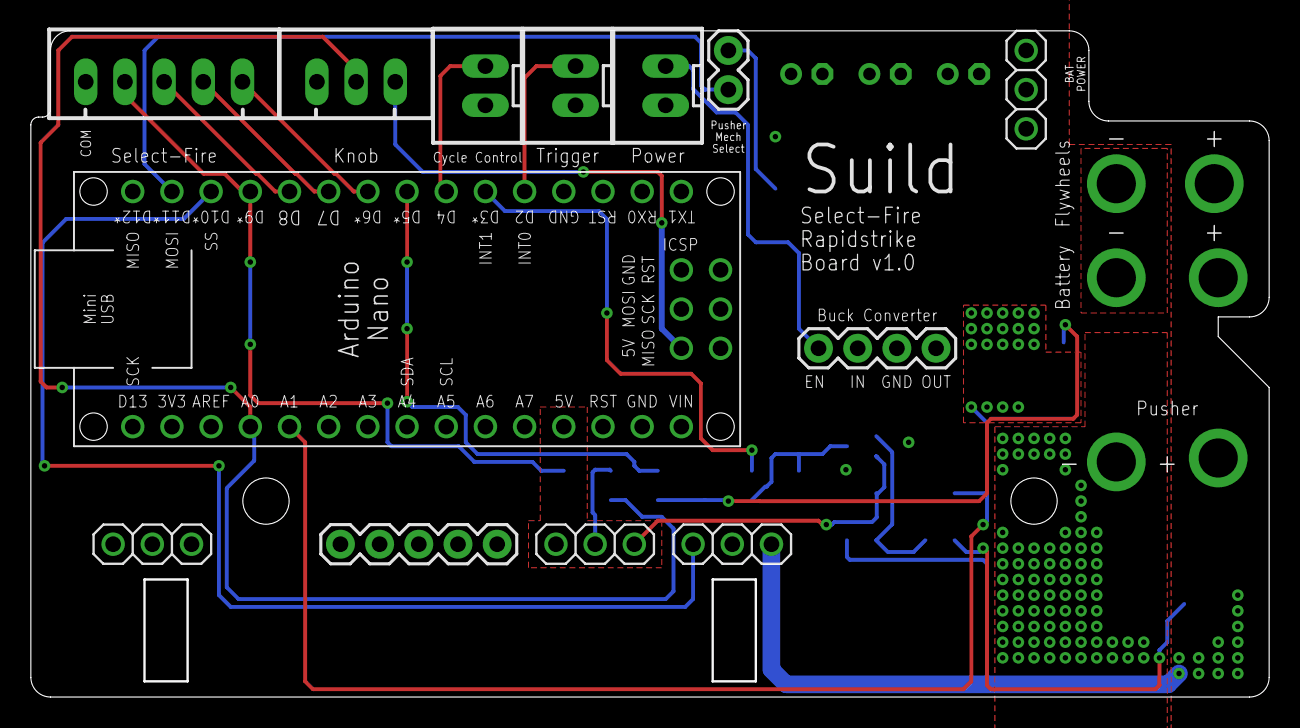
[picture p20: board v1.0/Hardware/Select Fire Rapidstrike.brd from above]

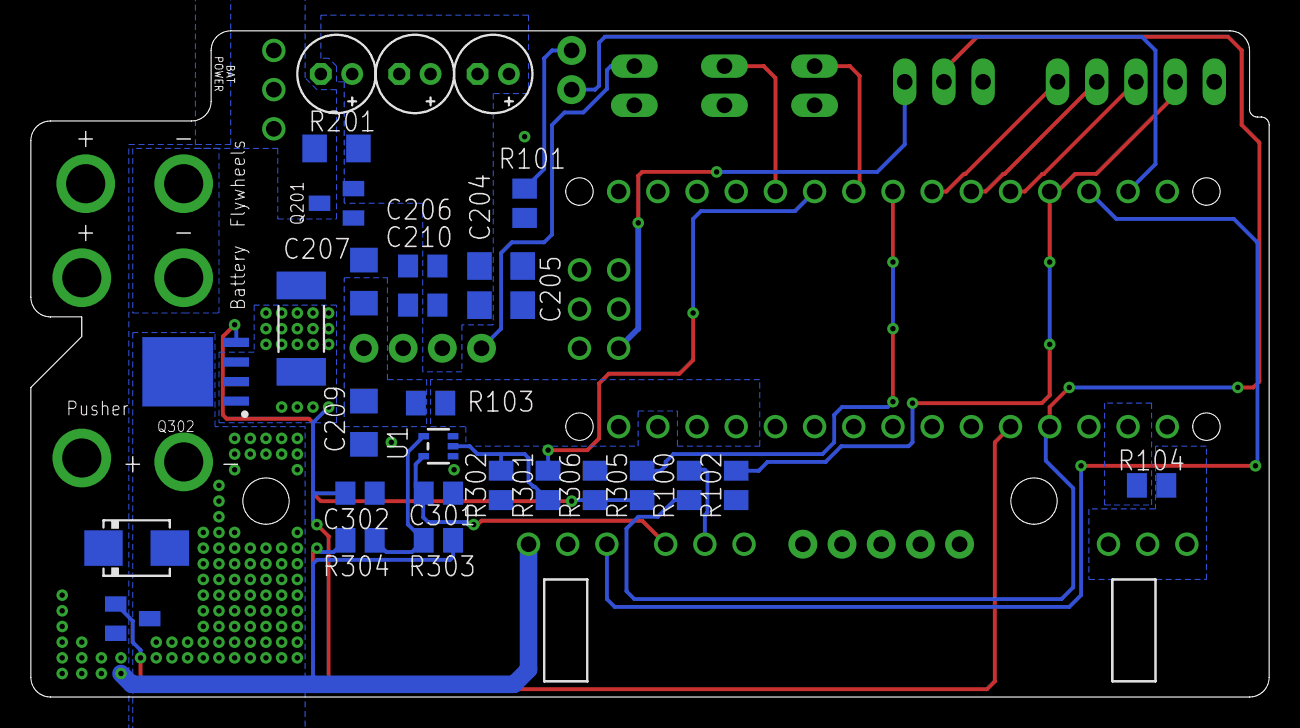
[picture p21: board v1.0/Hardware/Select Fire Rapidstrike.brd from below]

Board: 2 copper layers, 80.3 x 43.2 mm, 50 parts (30 on the bottom side), 26 nets.

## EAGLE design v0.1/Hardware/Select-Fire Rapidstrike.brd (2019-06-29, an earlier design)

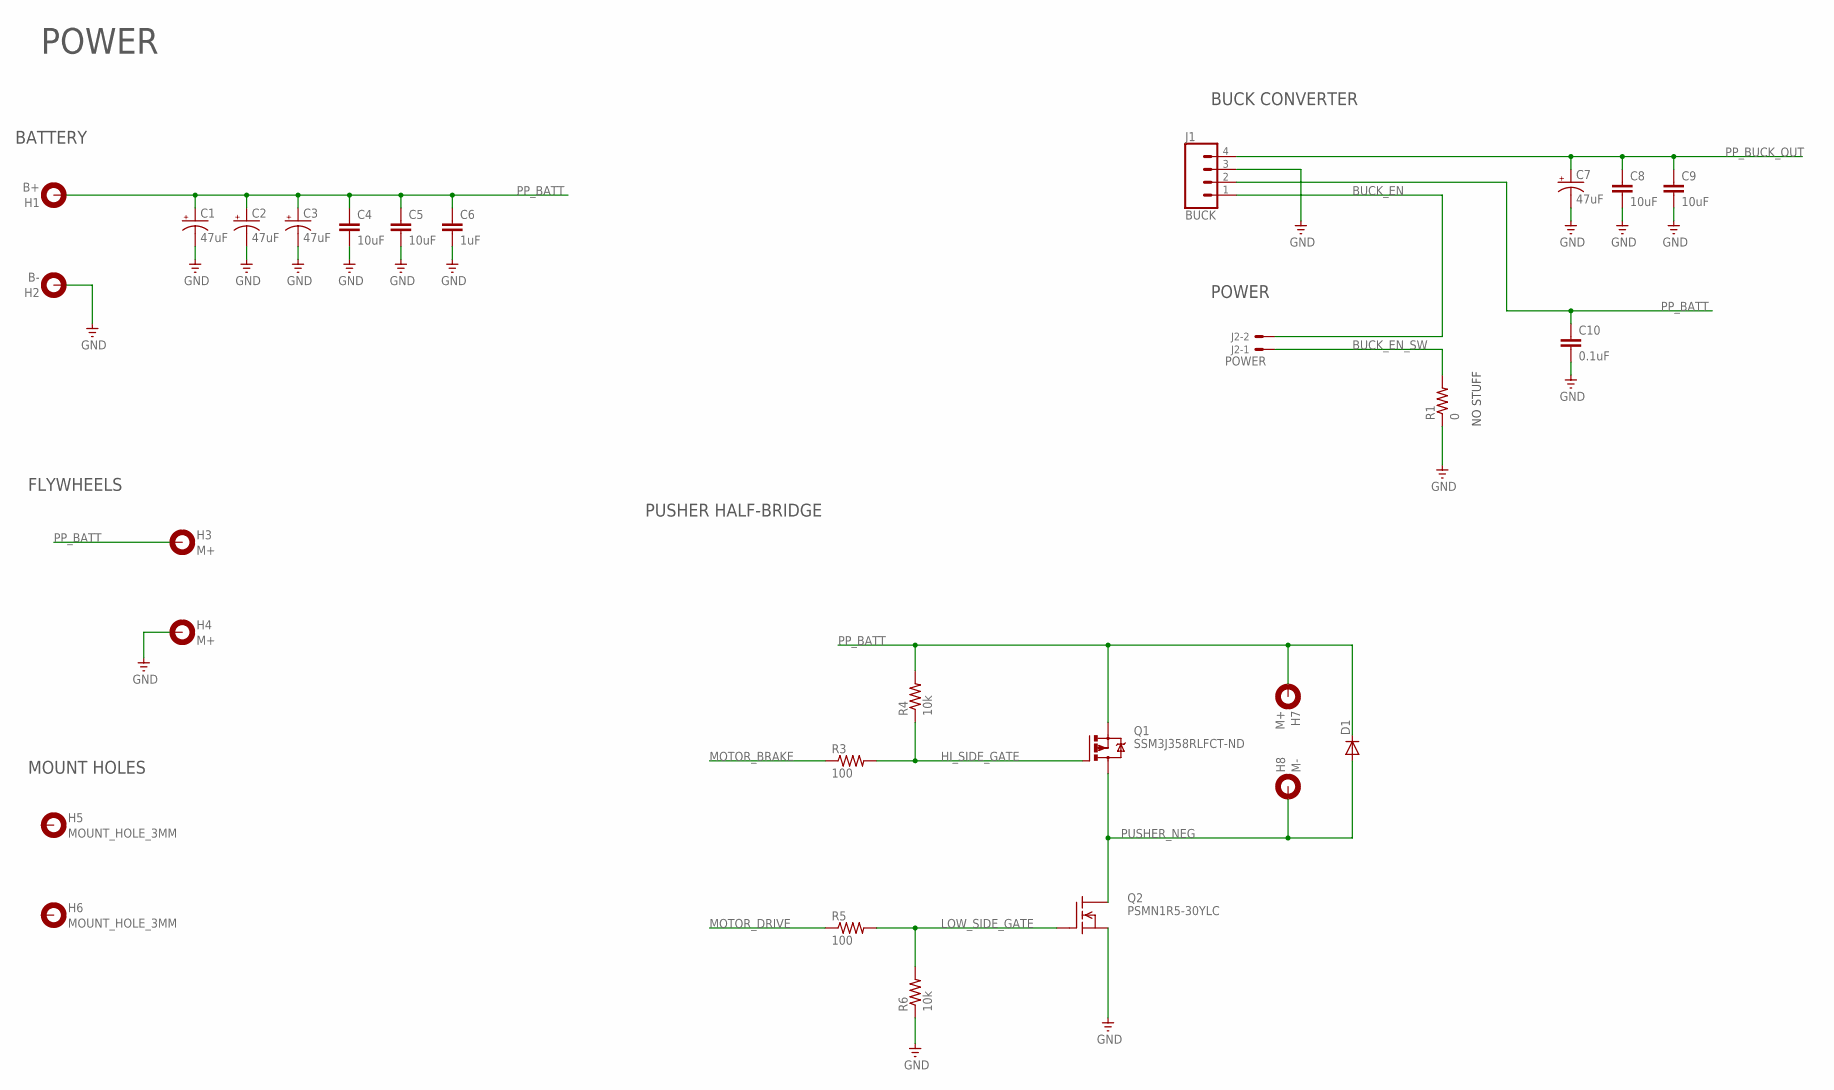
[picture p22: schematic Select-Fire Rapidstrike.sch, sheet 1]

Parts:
C1, C2, C3, C7: 47uF; E2-5
C4, C5, C8, C9: 10uF; C1206
C6: 1uF; C0805
C10: 0.1uF; C0805
D1: S2A; DO214AA
H1: B+; MOUNT-HOLE-2.5MM
H2: B-; MOUNT-HOLE-2.5MM
H3, H4, H7: M+; MOUNT-HOLE-2.5MM
H5, H6: MOUNT_HOLE_3MM
H8: M-; MOUNT-HOLE-2.5MM
J1: BUCK; 1X04
J2: POWER; JST-XH-02-PACKAGE-LONG-PAD
Q1: SSM3J358RLFCT-ND; SOT-23
Q2: PSMN1R5-30YLC; TO127P600X120-5N
R1: 0; M0805
R3, R5: 100; M0805
R4, R6: 10k; M0805

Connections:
BUCK_EN: J1.1, J2.2
BUCK_EN_SW: J2.1, R1.2
GND: C1.-, C2.-, C3.-, C4.2, C5.2, C6.2, C7.-, C8.2, C9.2, C10.2, H2.P$1, H4.P$1, J1.3, Q2.1 (S), Q2.2 (S), Q2.3 (S), R1.1, R6.1; also elsewhere on the board
HI_SIDE_GATE: Q1.1 (G), R3.2, R4.1
LOW_SIDE_GATE: Q2.4 (G), R5.2, R6.2
MOTOR_BRAKE: R3.1; also elsewhere on the board
MOTOR_DRIVE: R5.1; also elsewhere on the board
PP_BATT: C1.+, C2.+, C3.+, C4.1, C5.1, C6.1, C10.1, D1.C, H1.P$1, H3.P$1, H7.P$1, J1.2, Q1.2 (S), R4.2; also elsewhere on the board
PP_BUCK_OUT: C7.+, C8.1, C9.1, J1.4; also elsewhere on the board
PUSHER_NEG: D1.A, H8.P$1, Q1.3 (D), Q2.5 (D)

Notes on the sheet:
PUSHER HALF-BRIDGE
NO STUFF
BUCK CONVERTER
POWER
BATTERY
FLYWHEELS
MOUNT HOLES

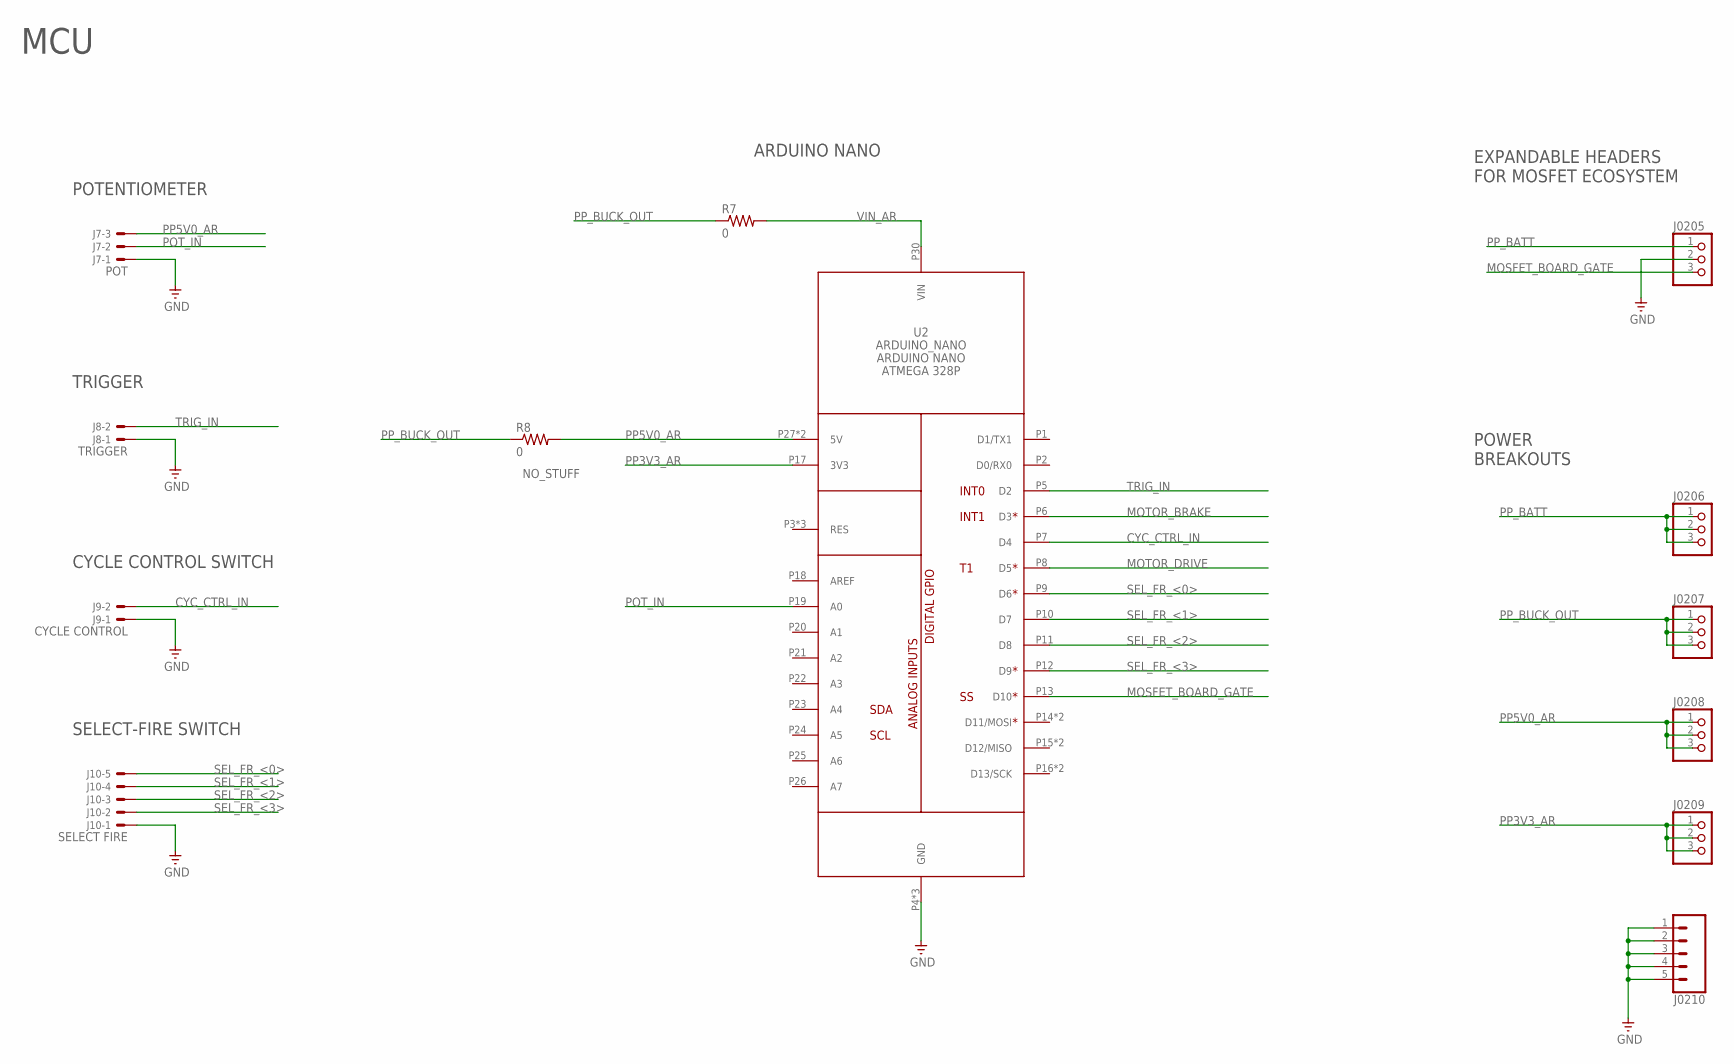
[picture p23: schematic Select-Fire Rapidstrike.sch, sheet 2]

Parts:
J7: POT; JST-XH-03-PACKAGE-LONG-PAD
J8: TRIGGER; JST-XH-02-PACKAGE-LONG-PAD
J9: CYCLE CONTROL; JST-XH-02-PACKAGE-LONG-PAD
J10: SELECT FIRE; JST-XH-05-PACKAGE-LONG-PAD
J0205, J0206, J0207, J0208, J0209: PINHD-1X3; 1X03
J0210: CONN_05; 1X05
R7, R8: 0; M0805
U2: ARDUINO_NANO

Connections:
CYC_CTRL_IN: J9.2, U2.P7 (D4)
GND: J7.1, J8.1, J9.1, J10.1, J0205.2, J0210.1, J0210.2, J0210.3, J0210.4, J0210.5, U2.P4 (GND), U2.P29 (GND), U2.P32 (GND); also elsewhere on the board
MOSFET_BOARD_GATE: J0205.3, U2.P13 (D10)
MOTOR_BRAKE: U2.P6 (D3); also elsewhere on the board
MOTOR_DRIVE: U2.P8 (D5); also elsewhere on the board
POT_IN: J7.2, U2.P19 (A0)
PP3V3_AR: J0209.1, J0209.2, J0209.3, U2.P17 (3V3)
PP5V0_AR: J7.3, J0208.1, J0208.2, J0208.3, R8.2, U2.P27 (5V), U2.P36 (5V)
PP_BATT: J0205.1, J0206.1, J0206.2, J0206.3; also elsewhere on the board
PP_BUCK_OUT: J0207.1, J0207.2, J0207.3, R7.1, R8.1; also elsewhere on the board
SEL_FR_<0>: J10.5, U2.P9 (D6)
SEL_FR_<1>: J10.4, U2.P10 (D7)
SEL_FR_<2>: J10.3, U2.P11 (D8)
SEL_FR_<3>: J10.2, U2.P12 (D9)
TRIG_IN: J8.2, U2.P5 (D2)
VIN_AR: R7.2, U2.P30 (VIN)

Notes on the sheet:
MCU
POTENTIOMETER
TRIGGER
CYCLE CONTROL SWITCH
ARDUINO NANO
SELECT-FIRE SWITCH
EXPANDABLE HEADERS FOR MOSFET ECOSYSTEM
POWER BREAKOUTS

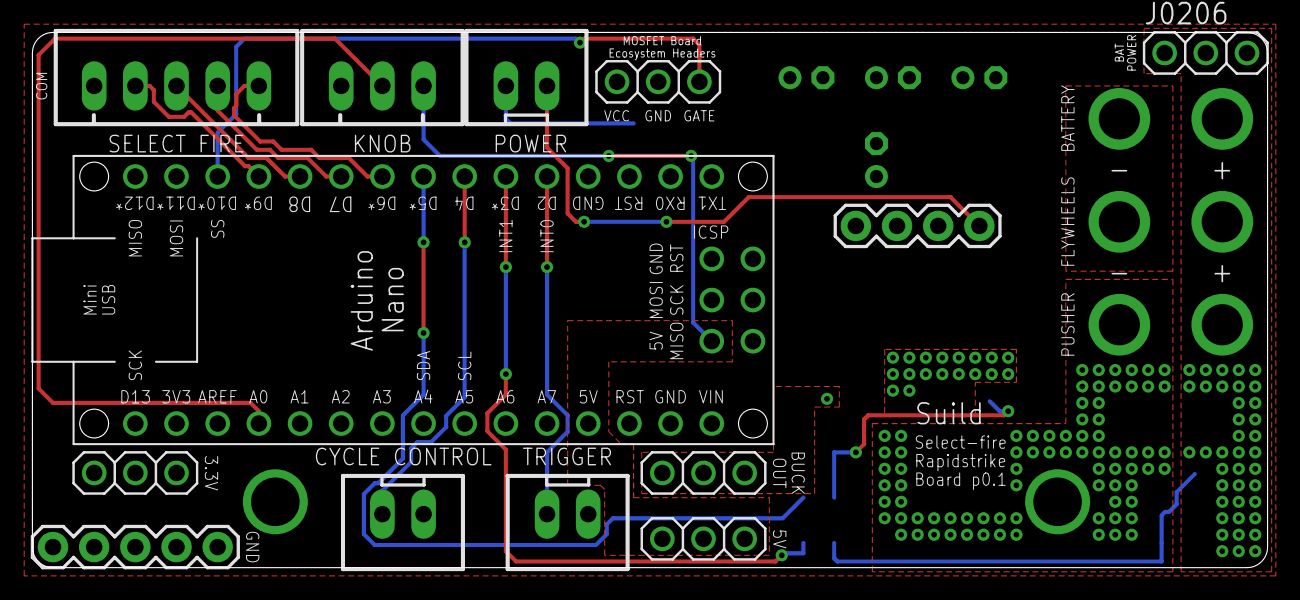
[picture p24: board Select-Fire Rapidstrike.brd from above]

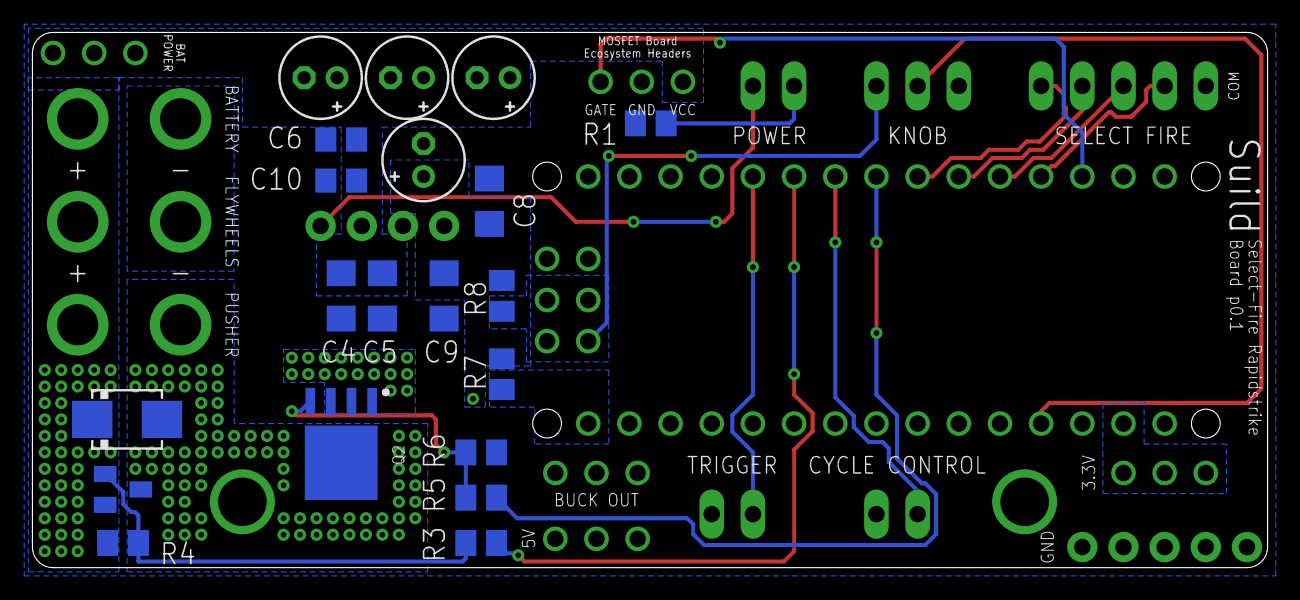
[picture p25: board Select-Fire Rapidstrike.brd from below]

Board: 2 copper layers, 76.2 x 33.0 mm, 41 parts (20 on the bottom side), 21 nets.

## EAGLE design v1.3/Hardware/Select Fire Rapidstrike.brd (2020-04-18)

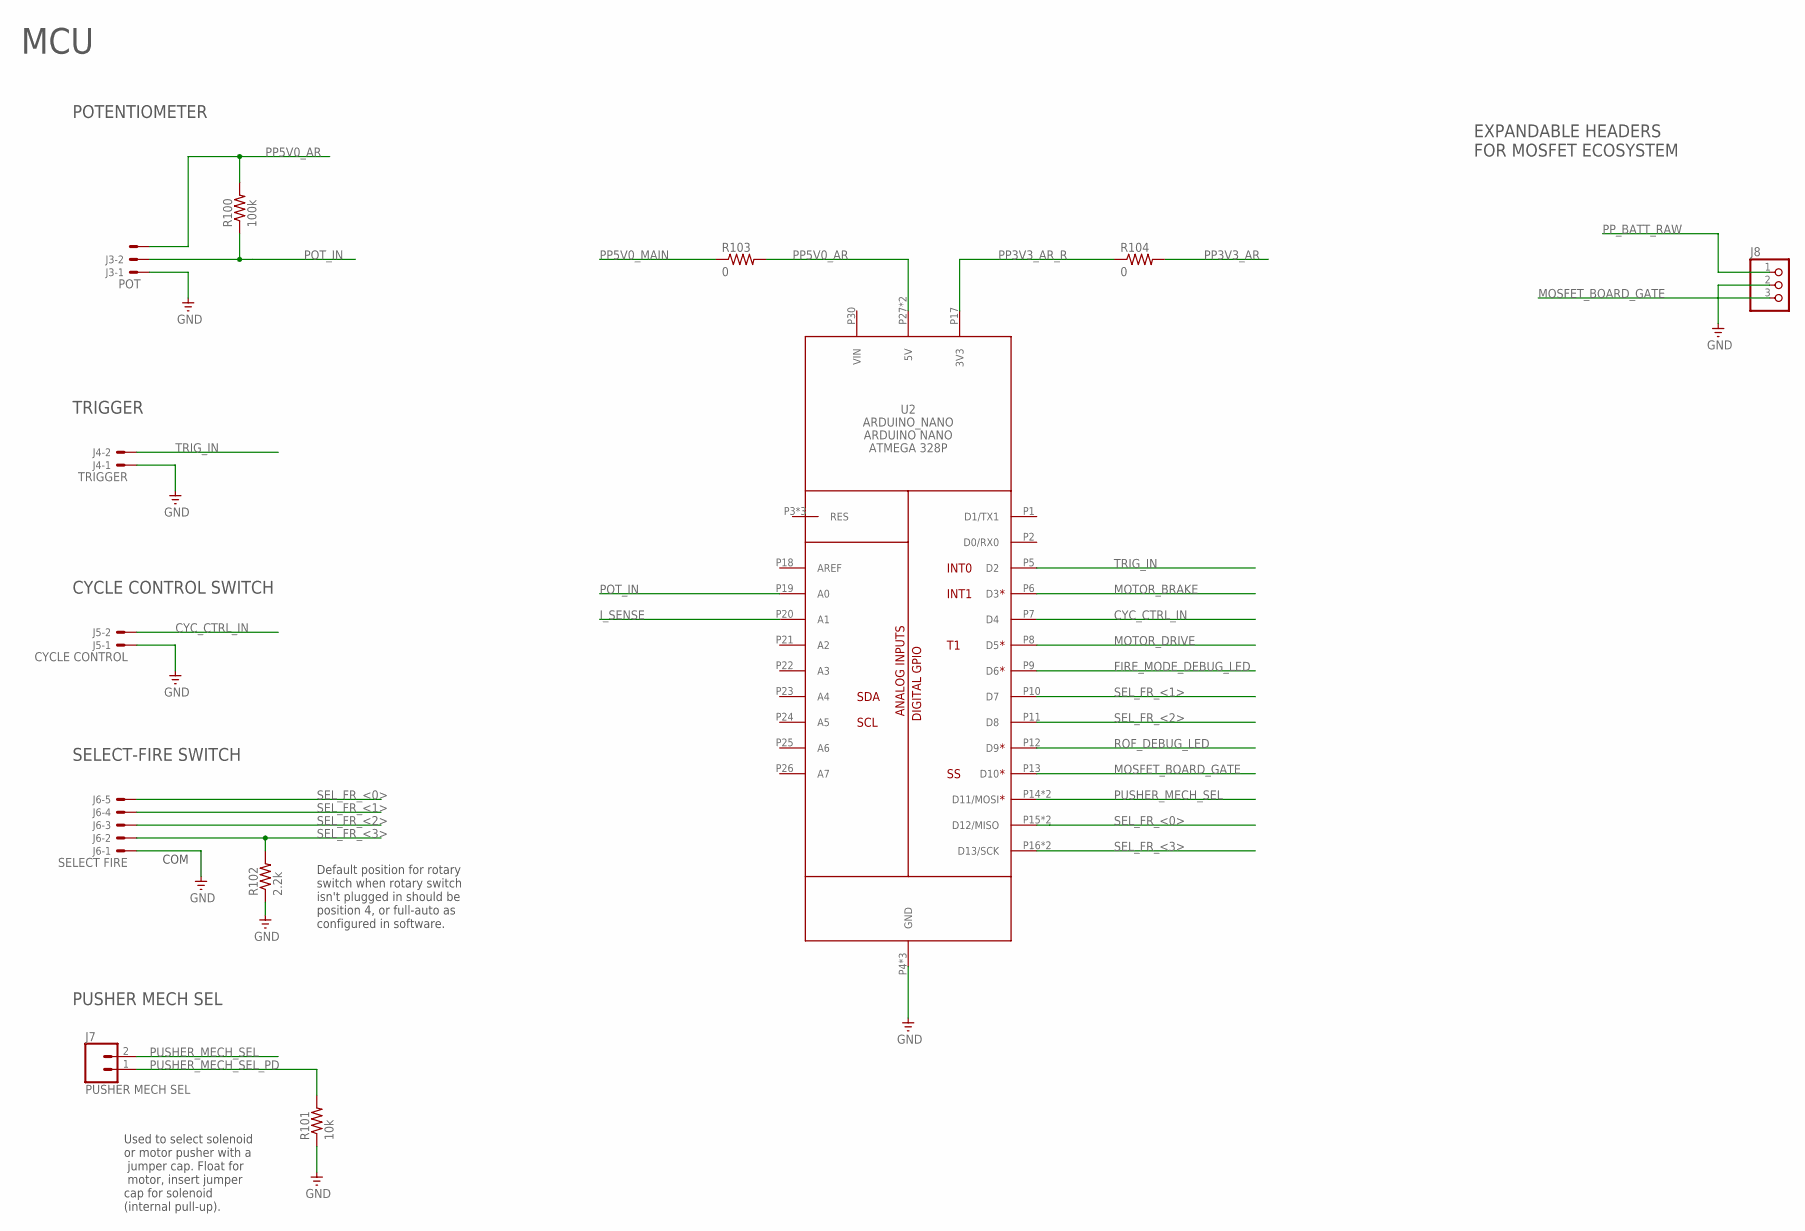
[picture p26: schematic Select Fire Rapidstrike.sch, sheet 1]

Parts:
J3: POT; JST-XH-03-PACKAGE-LONG-PAD
J4: TRIGGER; JST-XH-02-PACKAGE-LONG-PAD
J5: CYCLE CONTROL; JST-XH-02-PACKAGE-LONG-PAD
J6: SELECT FIRE; JST-XH-05-PACKAGE-LONG-PAD
J7: PUSHER MECH SEL; 1X02
J8: PINHD-1X3; 1X03
R100: 100k; M0805
R101: 10k; M0805
R102: 2.2k; M0805
R103, R104: 0; M0805
U2: ARDUINO_NANO

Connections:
CYC_CTRL_IN: J5.2, U2.P7 (D4); also elsewhere on the board
FIRE_MODE_DEBUG_LED: U2.P9 (D6); also elsewhere on the board
GND: J3.1, J4.1, J5.1, J6.1, J8.2, R101.1, R102.1, U2.P4 (GND), U2.P29 (GND), U2.P32 (GND); also elsewhere on the board
I_SENSE: U2.P20 (A1); also elsewhere on the board
MOSFET_BOARD_GATE: J8.3, U2.P13 (D10)
MOTOR_BRAKE: U2.P6 (D3); also elsewhere on the board
MOTOR_DRIVE: U2.P8 (D5); also elsewhere on the board
POT_IN: J3.2, R100.1, U2.P19 (A0)
PP3V3_AR: R104.2; also elsewhere on the board
PP3V3_AR_R: R104.1, U2.P17 (3V3)
PP5V0_AR: J3.3, R100.2, R103.2, U2.P27 (5V), U2.P36 (5V); also elsewhere on the board
PP5V0_MAIN: R103.1; also elsewhere on the board
PP_BATT_RAW: J8.1; also elsewhere on the board
PUSHER_MECH_SEL: J7.2, U2.P14 (D11/MOSI), U2.P34 (D11/MOSI)
PUSHER_MECH_SEL_PD: J7.1, R101.2
ROF_DEBUG_LED: U2.P12 (D9); also elsewhere on the board
SEL_FR_<0>: J6.5, U2.P15 (D12/MISO), U2.P35 (D12/MISO)
SEL_FR_<1>: J6.4, U2.P10 (D7)
SEL_FR_<2>: J6.3, U2.P11 (D8)
SEL_FR_<3>: J6.2, R102.2, U2.P16 (D13/SCK), U2.P33 (D13/SCK)
TRIG_IN: J4.2, U2.P5 (D2); also elsewhere on the board

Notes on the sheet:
MCU
POTENTIOMETER
TRIGGER
CYCLE CONTROL SWITCH
SELECT-FIRE SWITCH
EXPANDABLE HEADERS FOR MOSFET ECOSYSTEM
PUSHER MECH SEL
Default position for rotary switch when rotary switch isn't plugged in should be position 4, or full-auto as configured in software.
Used to select solenoid or motor pusher with a jumper cap. Float for motor, insert jumper cap for solenoid (internal pull-up).
COM

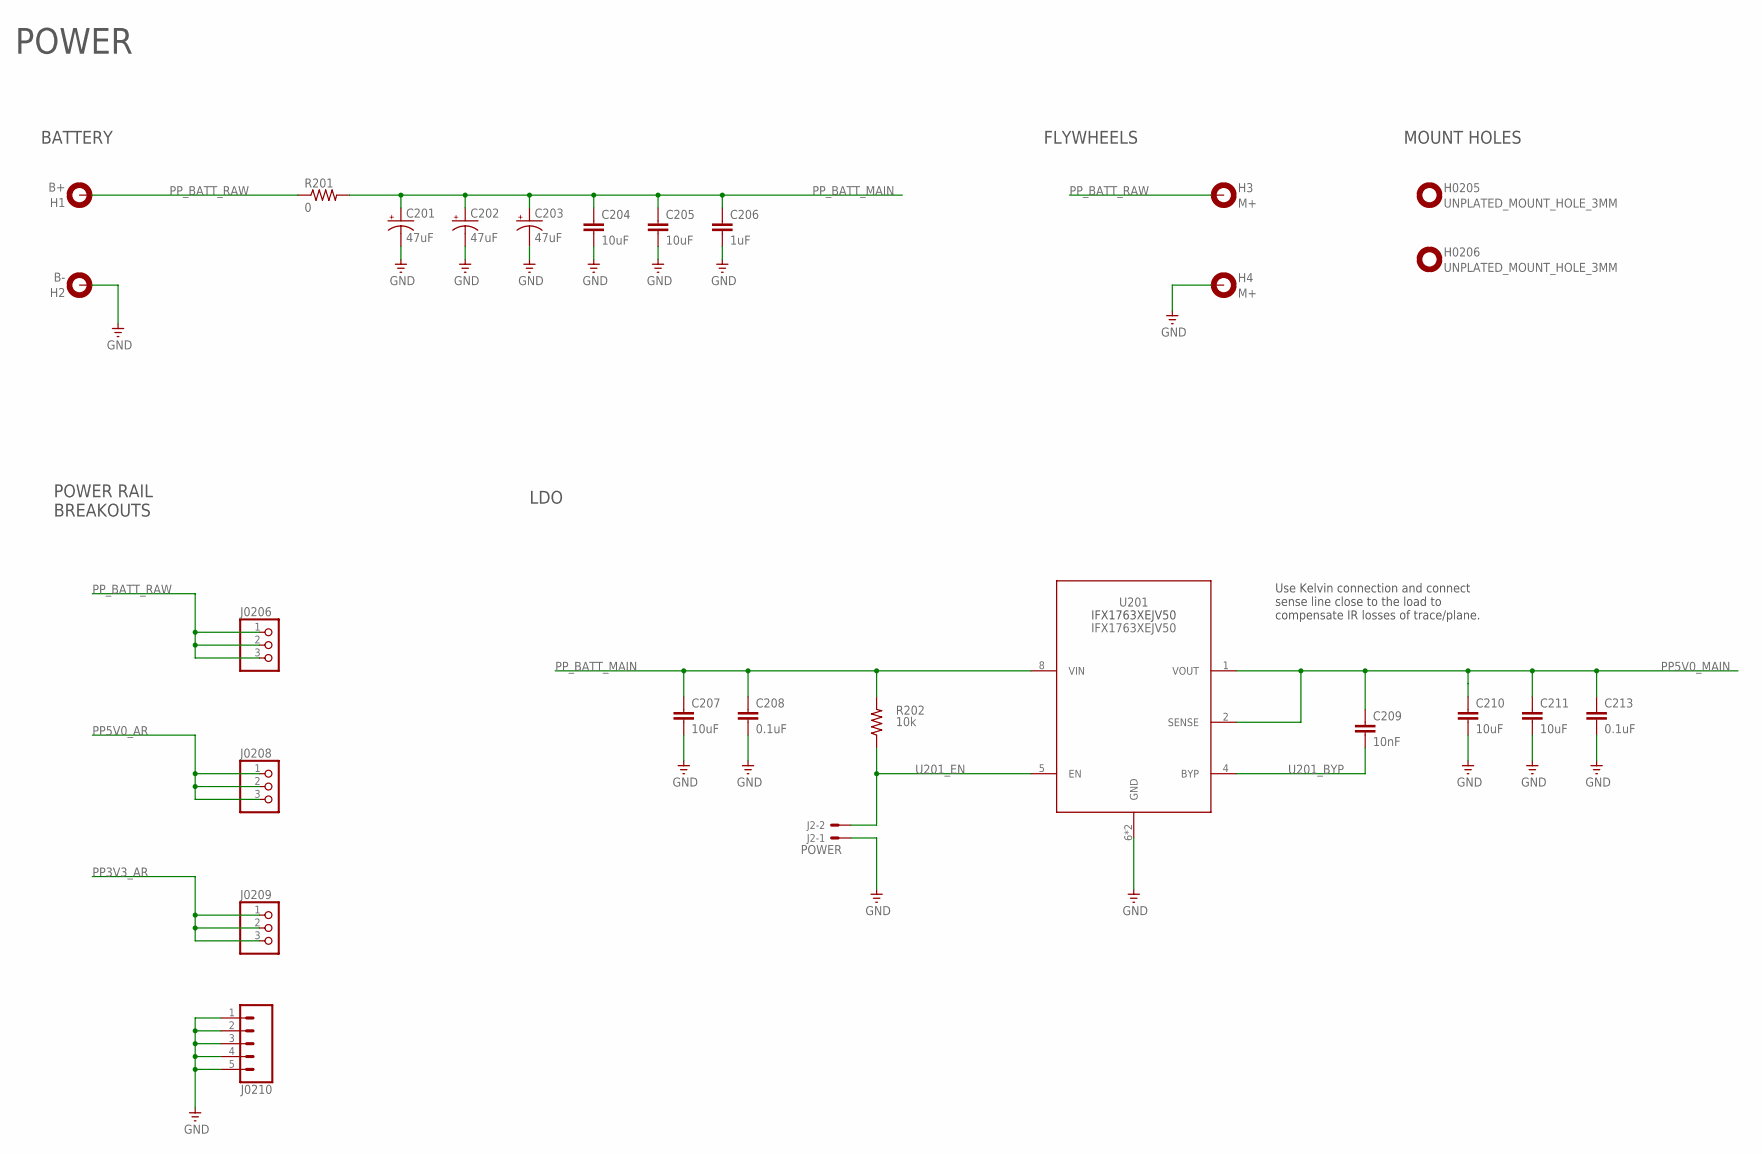
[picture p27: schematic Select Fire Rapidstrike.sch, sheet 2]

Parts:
C201, C202, C203: 47uF; E2-5
C204, C205, C207, C210, C211: 10uF; C1206
C206: 1uF; C0805
C208, C213: 0.1uF; C0805
C209: 10nF; C0805
H1: B+; MOUNT-HOLE-2.5MM
H2: B-; MOUNT-HOLE-2.5MM
H3, H4: M+; MOUNT-HOLE-2.5MM
H0205, H0206: UNPLATED_MOUNT_HOLE_3MM
J2: POWER; JST-XH-02-PACKAGE-LONG-PAD
J0206, J0208, J0209: PINHD-1X3; 1X03
J0210: CONN_05; 1X05
R201: 0; M0805
R202: 10k; M0805
U201: IFX1763XEJV50; PG-DSO-8

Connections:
GND: C201.-, C202.-, C203.-, C204.2, C205.2, C206.2, C207.2, C208.2, C210.2, C211.2, C213.2, H2.P$1, H4.P$1, J2.1, J0210.1, J0210.2, J0210.3, J0210.4, J0210.5, U201.6 (GND), U201.BODY (GND); also elsewhere on the board
PP3V3_AR: J0209.1, J0209.2, J0209.3; also elsewhere on the board
PP5V0_AR: J0208.1, J0208.2, J0208.3; also elsewhere on the board
PP5V0_MAIN: C209.1, C210.1, C211.1, C213.1, U201.1 (VOUT), U201.2 (SENSE); also elsewhere on the board
PP_BATT_MAIN: C201.+, C202.+, C203.+, C204.1, C205.1, C206.1, C207.1, C208.1, R201.2, R202.2, U201.8 (VIN)
PP_BATT_RAW: H1.P$1, H3.P$1, J0206.1, J0206.2, J0206.3, R201.1; also elsewhere on the board
U201_BYP: C209.2, U201.4 (BYP)
U201_EN: J2.2, R202.1, U201.5 (EN)

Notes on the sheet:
BATTERY
FLYWHEELS
MOUNT HOLES
POWER
POWER RAIL BREAKOUTS
LDO
Use Kelvin connection and connect sense line close to the load to compensate IR losses of trace/plane.

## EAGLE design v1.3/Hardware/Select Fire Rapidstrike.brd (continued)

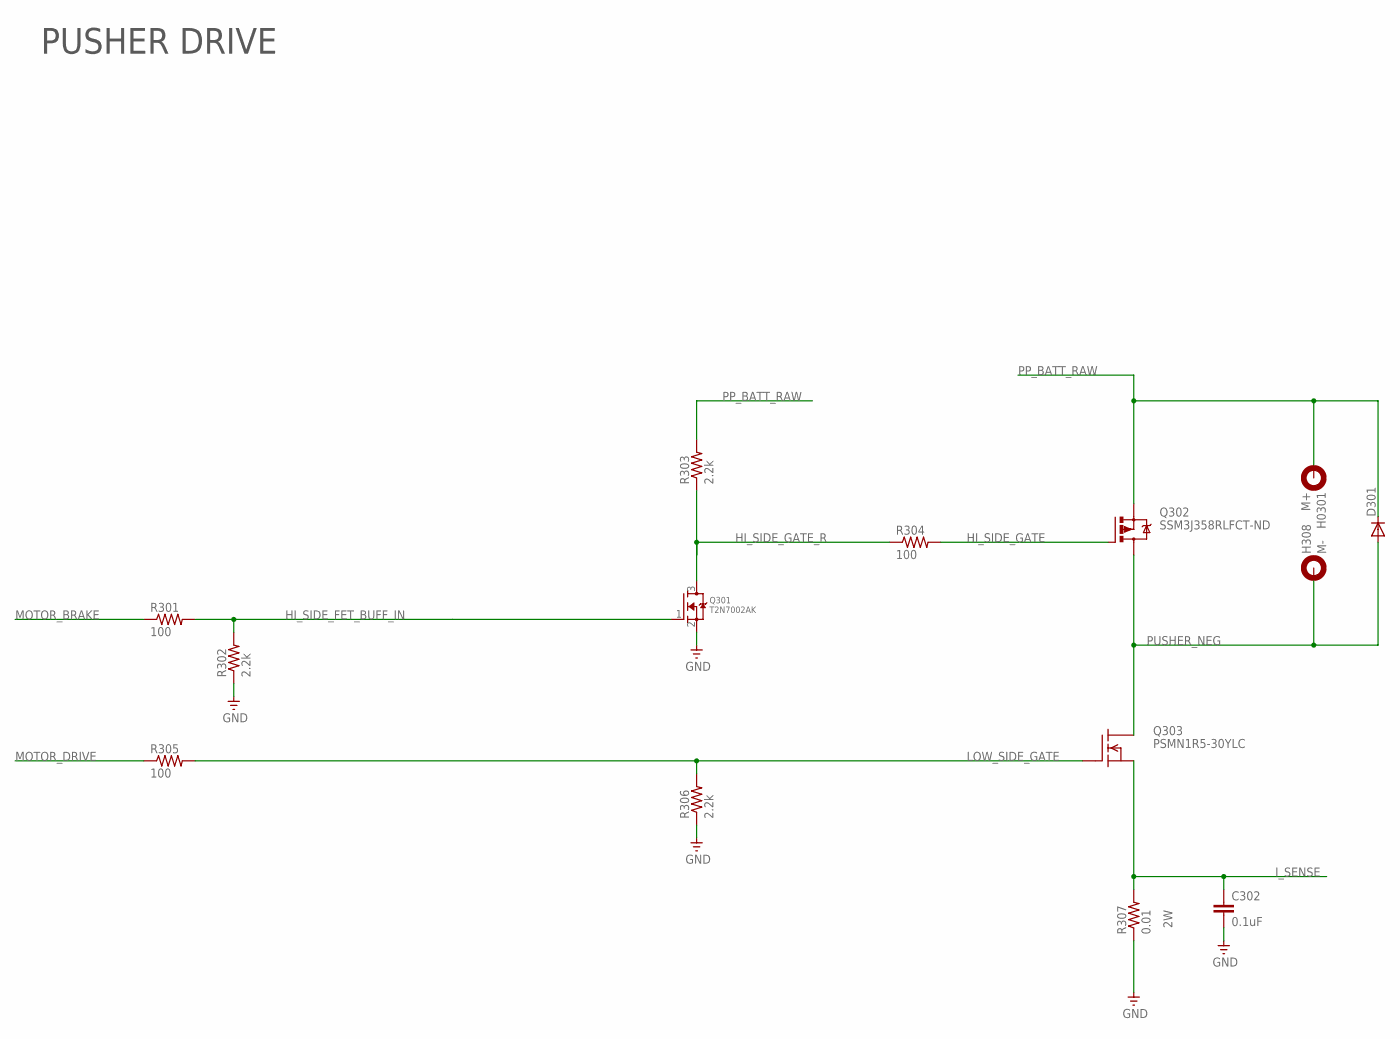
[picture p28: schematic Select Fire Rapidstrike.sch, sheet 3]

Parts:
C302: 0.1uF; C0805
D301: S2A; DO214AA
H0301: M+; MOUNT-HOLE-2.5MM
H308: M-; MOUNT-HOLE-2.5MM
Q301: T2N7002AK; SOT23
Q302: SSM3J358RLFCT-ND; SOT-23
Q303: PSMN1R5-30YLC; TO127P600X120-5N
R301, R304, R305: 100; M0805
R302, R303, R306: 2.2k; M0805
R307: 0.01; R2512

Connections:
GND: C302.2, Q301.2 (S), R302.1, R306.1, R307.1; also elsewhere on the board
HI_SIDE_FET_BUFF_IN: Q301.1 (G), R301.2, R302.2
HI_SIDE_GATE: Q302.1 (G), R304.2
HI_SIDE_GATE_R: Q301.3 (D), R303.1, R304.1
I_SENSE: C302.1, Q303.1 (S), Q303.2 (S), Q303.3 (S), R307.2; also elsewhere on the board
LOW_SIDE_GATE: Q303.4 (G), R305.2, R306.2
MOTOR_BRAKE: R301.1; also elsewhere on the board
MOTOR_DRIVE: R305.1; also elsewhere on the board
PP_BATT_RAW: D301.C, H0301.P$1, Q302.2 (S), R303.2; also elsewhere on the board
PUSHER_NEG: D301.A, H308.P$1, Q302.3 (D), Q303.5 (D)

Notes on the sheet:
PUSHER DRIVE


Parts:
DS401, DS402, DS403: LTST-C171GKT; CHIPLED_0805
DS404, DS405: LTST-C170AKT; CHIPLED_0805
DS406: LTST-C171TBKT; CHIPLED_0805
DS407: LTST-C171KSKT; CHIPLED_0805
R401, R402, R403, R407: 150; M0805
R404, R405: 300; M0805
R406: 165; M0805

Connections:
CYC_CTRL_IN: R403.1; also elsewhere on the board
FIRE_MODE_DEBUG_LED: DS407.A; also elsewhere on the board
GND: R401.1, R404.1, R405.1, R406.1, R407.1; also elsewhere on the board
LED_DS401: DS401.C, R401.2
LED_DS402: DS402.C, R402.2
LED_DS403: DS403.C, R403.2
LED_DS404: DS404.C, R404.2
LED_DS405: DS405.C, R405.2
LED_DS406: DS406.C, R406.2
LED_DS407: DS407.C, R407.2
MOTOR_BRAKE: DS404.A; also elsewhere on the board
MOTOR_DRIVE: DS405.A; also elsewhere on the board
PP5V0_AR: DS401.A, DS402.A, DS403.A; also elsewhere on the board
ROF_DEBUG_LED: DS406.A; also elsewhere on the board
TRIG_IN: R402.1; also elsewhere on the board

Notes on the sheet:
DEBUG LEDS
Fire mode debug LED. Changes brightness depending on the mode. In the future, I want an RGB LED. Helps to verify rotary switch wiring and functionality.
Debug LEDs for switches. Turns on when switches are pressed, off when not. Helps to verify switches, making sure that the entire path is all good. These LEDs are tied to inputs that can only sink current through the switches, so they must be supplied with a current source.
Rate of fire debug LED. Turns brighter for higher RoF. Helps to verify pot wiring and functionality.
Pusher drive debug LEDs. They turn on when the FET turns on, off when off. Helps verify software and FET driving network.
SWITCHES
ARDUINO POWER
PUSHER
RATE OF FIRE
FIRE MODE



Board: 2 copper layers, 80.3 x 43.2 mm, 66 parts (47 on the bottom side), 36 nets.

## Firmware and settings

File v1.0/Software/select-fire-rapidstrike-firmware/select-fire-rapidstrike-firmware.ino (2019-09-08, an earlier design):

#include <Arduino.h>
#include <timer.h>
#include <JC_Button.h>
#include <CircularBuffer.h>

//
// Macros and vars for trigger and cycle control switch stuff
#define TRIGGER_PIN 2
#define CYC_CTRL_PIN 4

//
// Macros for FET pins
#define HIGH_SIDE_PIN 3			
#define LOW_SIDE_PIN 5

// Macros to improve readability of FET transition functions
#define ON true
#define OFF false

// Macros for pusher drive state
#define PUSHER_DRIVE_STATE_OFF 0
#define PUSHER_DRIVE_STATE_BRAKE 1
#define PUSHER_DRIVE_STATE_ON 2

// Macros for current sensing
#define CURRENT_SENSE_PIN 1
#define SENSE_RESISTANCE 0.01
#define ARDUINO_SUPPLY_VOLTAGE 5.0
#define NUM_OF_SAMPLES_FOR_DIFFERENTIATION 3

//
// Macros and vars for variable fire rate control values
#define POT_PIN 0

//
// Macros for fire values
#define SAFETY 0
#define SEMI_AUTO 1
#define BURST_FIRE 2
#define FULL_AUTO 3

#define BURST_FIRE_LENGTH 3

//
// Macros to keep track of fire mechanisms
// Improve readability of pusher mechanism logic
#define PUSHER_MOTOR_FIRING_MECHANISM 0
#define SOLENOID_FIRING_MECHANISM 1

// Pin that is used to select pusher mechanism. Jumper off for motor, jumper on 
// for solenoid. Uses internal pullup so HIGH = motor, LOW = solenoid
#define PUSHER_MECHANISM_SELECT_PIN 11

//
// Macros and vars for rotary switch stuff
#define ROT_SW_SAFETY_PIN 6
#define ROT_SW_SEMI_AUTO_PIN 7
#define ROT_SW_BURST_FIRE_PIN 8
#define ROT_SW_FULL_AUTO_PIN 9

#define NUM_OF_ROT_SW_PINS 4
// Array of all rotary switch pins so it's easier to iterate through all of them
const uint8_t ROT_SW_PINS[] = {ROT_SW_SAFETY_PIN, ROT_SW_SEMI_AUTO_PIN, ROT_SW_BURST_FIRE_PIN, ROT_SW_FULL_AUTO_PIN};


// Function prototypes incase you're not using Arduino IDE 
// I'd highly recommend using Platform.io instead of Arduino IDE
void initSerial(void);
void initFETPins(void);

void controlMotors();
bool handleComplementaryFETTransition();
void turnOffAllFETs();
void setFETsForBraking();
void setFETsForOn();
void transitionHighSideFET(bool);
void transitionLowSideFET(bool);

void handleCycleControl();

void handleFiring();

uint8_t getRotSwPos(uint8_t rotSwPins[], uint8_t);
void setCurrentFiremode(uint8_t);
void printCurrentFireMode();
void setPusherMechanism();
void setRateOfFire();
void setDartsToFire();

void handlePusherMotorFiring();
void updatePusherMotorTiming();
bool turnOnPusherMotor();
void handlePusherMotorSemiAutoAndBurst();
void handlePusherMotorFullAuto();

void handleSolenoidFiring();
void updateSolenoidTiming();
bool handleSolenoidTuronOn();
void handleSolenoidSemiAutoAndBurst();
void handleSolenoidFullAuto();

float analogReadingToVoltage();
float voltageToCurrent(float);
void updateCurrentSenseValues(float);

Button trgSw (TRIGGER_PIN, 50, true, true);
Button cycCtrlSw (CYC_CTRL_PIN, 50, true, true);

// variables for managing all of firing state
struct firingState {
	uint8_t currentPusherState = PUSHER_DRIVE_STATE_OFF;
	// should only be mutated in controlMotors(), but can be accessed anywhere
	uint8_t targetPusherState = PUSHER_DRIVE_STATE_OFF;	

  // Switch states
  bool wasTriggerPulled = false;
  bool isTriggerPressed = false;

  bool isCycCtrlSwPressed = false;
  bool wasCycCtrlSwPressed = false;

	// Keep track of firing mechanism, solenoid or pusher. This is updated on 
	// trigger pull by reading the jumper
	bool pusherMechanism = PUSHER_MOTOR_FIRING_MECHANISM;

	uint8_t currentFireMode = FULL_AUTO;

	// Keep track if pusher is firing. I can't just check if the pusher is being 
	// powered because sometimes, the pusher is firing but off (for example, a
	// solenoid returning to its retracted position)
	bool isFiring = false;

	// Keeps track of how many darts to fire in semi- and burst-fire modes
	uint8_t dartsToFire = 0;

	// Keep track of how many darts have been fired
	uint8_t dartsFired = 0;

	// Rate of fire from 0 to 100 (100 fastest)
	uint8_t rateOfFire = 100;

	// Off time between shots when in pusher motor mode. Higher rate of fire means
	// higher off time between shots. Units in ms
	uint8_t pusherMotorOffTime = 0;

	// Duty cyle for solenoid firing. Different fire rates will be a factor of 
	// this. Units are percent
	const uint8_t SOLENOID_DUTY_CYCLE = 60;

	// Time that solenoid is powered when firing, in ms
	uint16_t solenoidOnTime = 35;

	// Time that solenoid is off when firing, in ms
	uint16_t solenoidOffTime = 15;

	// Timer to keep track of when to turn on/off the pusher
	Timer<> firingTimer = timer_create_default();


} firingState;

// variables for managing all of MOSFET state
// these values should only be mutated in a FET function
// I should probably abstract this into its own class
struct fetState {
	// Timer for managing shoot through delay. 
	// From this lib: https://github.com/contrem/arduino-timer
	// Quick description: Non-blocking library for delaying function calls
	Timer<> shootThroughProtectionTimer = timer_create_default();

	// Shoot through delay, in ms. 
	// This value is read-only, so no need to store it in dynamic memory
	const uint8_t SHOOT_THROUGH_DELAY = 1;

	// Flag to indicate that a complementary FET transition has begun
	// This is mainly so multiple shoot-through timers doesn't start 
	bool hasComplementaryTransitionBegun = false;		

	bool currentHighSideFETState = OFF;
	bool targetHighSideFETState = OFF;

	bool currentLowSideFETState = OFF;
	bool targetLowSideFETState = OFF;

} fetState;

// Struct to keep track of sense resitors values for differentiation
struct currentSenseState {
	const uint8_t SAMPLE_DELAY = 15;	// Current sample delay, in ms

	// Current limit for OCP
	// If this limit is hit for longer than MAX_OCP_SAMPLES samples, then load 
	// will be turned off
	// This is only for flywheel operation
	const uint8_t OCP_CURRENT_LIMIT = 5;

	// If more than OCP_CURRENT_LIMIT is observed for MAX_OCP_SAMPLES samples, 
	// power to the load will be cut
	const uint8_t MAX_OCP_SAMPLES = 25;

	// Flag if OCP Threshold counter hit limit
	// flag to see if too much current. If this flag is true, load will turn off
	// in controlMotors()
	bool isTooMuchCurrent = false;

	// Counter to keep track how many times current is above OCP_CURRENT_LIMIT
	// Gets reset to 0 if current is less than OCP_CURRENT_LIMIT
	uint8_t ocpThresholdHitCounter = 0;

	// const uint8_t NUM_OF_SAMPLES_FOR_DIFFERENTIATION = 5;

	// Paralleling FIFO buffer for sample time (x) and current (y)
	CircularBuffer<float, NUM_OF_SAMPLES_FOR_DIFFERENTIATION> sampleTimeBuffer;	
	CircularBuffer<float, NUM_OF_SAMPLES_FOR_DIFFERENTIATION> currentValues;

	Timer<> currentSenseTimer = timer_create_default();

	// -1 instantaneousChangeInCurrent means that this value isn't ready yet
	// instantaneousChangeInCurrent might not be ready if there aren't enough
	// samples
	float instantaneousChangeInCurrent = -1;

	float instantaneousCurrentDraw = -1;
} currentSenseState;

void setup() {
	initSerial();
	initFETPins();
	initRotSwPins();

	pinMode(PUSHER_MECHANISM_SELECT_PIN, INPUT_PULLUP);

	trgSw.begin();
	cycCtrlSw.begin();

	// Start timer that executes monitorCurrent() every 
	// currentSenseState.SAMPLE_DELAY ms
	currentSenseState.currentSenseTimer
		.every(currentSenseState.SAMPLE_DELAY, monitorCurrent);
}

void loop() {
	fetState.shootThroughProtectionTimer.tick();
	currentSenseState.currentSenseTimer.tick();
	firingState.firingTimer.tick();

	handleTriggerPull();
	handleCycleControl();
	handleFiring();
 	controlMotors();

  
}

void initSerial() {
	Serial.begin(9600);
	while(!Serial){}
	Serial.println("Serial communication established");
}

void initFETPins() {
	pinMode(HIGH_SIDE_PIN, OUTPUT);
	pinMode(LOW_SIDE_PIN, OUTPUT);

	firingState.targetPusherState = PUSHER_DRIVE_STATE_OFF;

	controlMotors();
}

void initRotSwPins() {
  // Set all rotary switch pins to inputs with pullups
  for (int i = 0; i < sizeof(ROT_SW_PINS)/sizeof(ROT_SW_PINS[0]); i++) {
    pinMode(ROT_SW_PINS[i], INPUT_PULLUP);
  }
}

// Directly handles driving the pusher, including shoot-through protection 
// Controls motors based on firingState currentPusherState and targetPusherState
void controlMotors() {
	// If too much current, cut off power to load and don't run anything else
	if (currentSenseState.isTooMuchCurrent) {
		Serial.println("OCP");

		turnOffAllFETs();
		
		firingState.targetPusherState = PUSHER_DRIVE_STATE_OFF;
    firingState.isFiring = false;

		return;
	}

	if (firingState.targetPusherState == PUSHER_DRIVE_STATE_OFF) {
    turnOffAllFETs();

    firingState.currentPusherState = PUSHER_DRIVE_STATE_OFF;

  // Targetstate requires MOSFETs to change state that's at risk of shoot-
  // through
  // When transition FETs where the FETs are complementary, here's the sequence: 
	// BRAKE -> OFF -> [shoot-through delay] -> ON 
	// (or)
	// ON -> OFF -> [shoot-through delay] -> BRAKE
  					// Nake sure pusher state changed
  } else if (firingState.currentPusherState != firingState.targetPusherState
  	&& !fetState.hasComplementaryTransitionBegun
  	// Make sure target pusher state results in a complementary FET state 
  	&& (firingState.targetPusherState == PUSHER_DRIVE_STATE_ON
  	|| firingState.targetPusherState == PUSHER_DRIVE_STATE_BRAKE)) {

   	turnOffAllFETs();

   	// Set flag to indicate that transition of FETs to a complementary state has
   	// begun
   	fetState.hasComplementaryTransitionBegun = true;

   	// Transition FETs to match their target state afte SHOOT_THROUGH_DELAY
   	fetState.shootThroughProtectionTimer
   		.in(fetState.SHOOT_THROUGH_DELAY, handleComplementaryFETTransition);
  }
}

// Actually drives FETs in complementary switching
bool handleComplementaryFETTransition() {
	if (firingState.targetPusherState == PUSHER_DRIVE_STATE_ON) {
		setFETsForOn();	
	} else if (firingState.targetPusherState == PUSHER_DRIVE_STATE_BRAKE) {
		setFETsForBraking();	
	}

	// Reset flag, complementary transition complete
 	fetState.hasComplementaryTransitionBegun = false;

 	// Target pusher state has been achieved
	firingState.currentPusherState = firingState.targetPusherState;

	return true;		//required by timer lib
}

void turnOffAllFETs() {
	transitionHighSideFET(OFF);
	transitionLowSideFET(OFF);	
}

void setFETsForBraking() {
	transitionHighSideFET(ON);
	transitionLowSideFET(OFF);	
}

void setFETsForOn() {
	transitionHighSideFET(OFF);
	transitionLowSideFET(ON);
}

// Abstracts away digitalWrites, helps make code more readable
void transitionHighSideFET(bool toTurnOn) {
	// transitioning high side FET can be confusing since the digitalWrite() must
	// be inverted
	digitalWrite(HIGH_SIDE_PIN, !toTurnOn);
}

// Abstracts away digitalWrites, helps make code more readable
void transitionLowSideFET(bool toTurnOn) {
	digitalWrite(LOW_SIDE_PIN, toTurnOn);
}

void handleTriggerPull() {
  trgSw.read();

  firingState.isTriggerPressed = trgSw.isPressed();
  firingState.wasTriggerPulled = trgSw.wasPressed();

}

void handleCycleControl() {
  cycCtrlSw.read();
  firingState.isCycCtrlSwPressed = cycCtrlSw.isPressed();
  firingState.wasCycCtrlSwPressed = cycCtrlSw.wasPressed();

  // Only count shots through cycle control if it's in pusher motor motde
  // if (firingState.wasCycCtrlSwPressed  
  // 	&& firingState.pusherMechanism == PUSHER_MOTOR_FIRING_MECHANISM) {

  //   firingState.dartsFired++;
  //   // Serial.println(firingState.dartsFired);
  // }
}

void handleFiring() {
	if (firingState.wasTriggerPulled) {
    const uint8_t ROT_SW_POS = getRotSwPos(ROT_SW_PINS, NUM_OF_ROT_SW_PINS);
		setCurrentFiremode(ROT_SW_POS);
		// printCurrentFireMode();

    setPusherMechanism();
    setRateOfFire();
    setDartsToFire();

    firingState.isFiring = true;

  }

  // If pusher in firing sequence
  if (firingState.isFiring) {
  	if (firingState.pusherMechanism == PUSHER_MOTOR_FIRING_MECHANISM) {
			handlePusherMotorFiring();
    } else if (firingState.pusherMechanism == SOLENOID_FIRING_MECHANISM) {
    	handleSolenoidFiring();
    }
  }
}

// Returns position of rotary switch in terms of which pin is connected to COM (pin is low)
uint8_t getRotSwPos(uint8_t rotSwPins[], uint8_t numOfRotSwPins) {
  for (int rotSwPin = 0; rotSwPin < NUM_OF_ROT_SW_PINS; rotSwPin++) {
    if (digitalRead(rotSwPins[rotSwPin]) == LOW) {
      return rotSwPins[rotSwPin];
    }
  }

}

void setCurrentFiremode(uint8_t ROT_SW_POS) {
  if (ROT_SW_POS == ROT_SW_SAFETY_PIN) {
    firingState.currentFireMode = SAFETY;
  } else if (ROT_SW_POS == ROT_SW_SEMI_AUTO_PIN) {
    firingState.currentFireMode = SEMI_AUTO;
  } else if (ROT_SW_POS == ROT_SW_BURST_FIRE_PIN) {
    firingState.currentFireMode = BURST_FIRE;
  } else if (ROT_SW_POS == ROT_SW_FULL_AUTO_PIN) {
    firingState.currentFireMode = FULL_AUTO;
  }
}

// Print fire modes over serial 
void printCurrentFireMode() {
  if (firingState.currentFireMode == SAFETY) {
      Serial.println("Safety");
    } else if (firingState.currentFireMode == SEMI_AUTO) {
      Serial.println("Single Shot");
    } else if (firingState.currentFireMode == BURST_FIRE) {
      Serial.println("Burst Fire");
    } else if (firingState.currentFireMode == FULL_AUTO) {
      Serial.println("Full Auto");
    }
}

// Sets pusher mechanism based on reading jumper pin (D11)
// If high (no jumper cap on), pusher mech is pusher
// If low (jumper cap on), pusher mech is solenoid
void setPusherMechanism() {
	if (digitalRead(PUSHER_MECHANISM_SELECT_PIN)) {
		firingState.pusherMechanism = PUSHER_MOTOR_FIRING_MECHANISM;
	} else {
		firingState.pusherMechanism = SOLENOID_FIRING_MECHANISM;
	}
}

void setRateOfFire() {
	uint8_t lowerLimitForRateOfFire = 1;
	uint8_t upperLimitForRateOfFire = 100;

	if (firingState.pusherMechanism == SOLENOID_FIRING_MECHANISM) {
		lowerLimitForRateOfFire = 20;
		upperLimitForRateOfFire = 35;
	}

	firingState.rateOfFire = map(
		analogRead(POT_PIN), 0, 1024, 
		upperLimitForRateOfFire, lowerLimitForRateOfFire);

	Serial.println(firingState.rateOfFire);
}

void setDartsToFire() {
  if (firingState.currentFireMode == SEMI_AUTO) {
    firingState.dartsToFire = 1;
  } else if (firingState.currentFireMode == BURST_FIRE) {
    firingState.dartsToFire = BURST_FIRE_LENGTH;
  }

  firingState.dartsFired = 0;
}

void handlePusherMotorFiring() {
	// Start motors and fining sequence upon trigger pull when not in safety mode
	if (firingState.wasTriggerPulled) {
		updatePusherMotorTiming();
		
		if (firingState.currentFireMode != SAFETY) {
			firingState.targetPusherState = PUSHER_DRIVE_STATE_ON;

		// Firemode is safety
		} else {
			firingState.targetPusherState = PUSHER_DRIVE_STATE_BRAKE;
			firingState.isFiring = false;
		}

	}

	// If cycle control was pressed
	if (firingState.wasCycCtrlSwPressed) {
		firingState.targetPusherState = PUSHER_DRIVE_STATE_BRAKE;

		// Firemode not safety, so probably fire more darts. Brake motors, then 
		// check if more darts should be fired. If more darts should be fired, power
		// pusher after a delay (this is dependant on rate of fire). 
		if (firingState.currentFireMode != SAFETY) {
			firingState.dartsFired++;

			// Firemode is full auto. Only kill motors if trigger isn't presseed
			if (firingState.currentFireMode == FULL_AUTO) {
				// Trigger isn't pressed, stop firing and brake motors
				if (!firingState.isTriggerPressed) {
					firingState.targetPusherState = PUSHER_DRIVE_STATE_BRAKE;
					firingState.isFiring = false;

					return; 
				}
			}

			// Firemode is semi-atuo. Stop firing and brake motors (because a shot has
			// been fired) if cycle control was pressed
			if (firingState.currentFireMode == SEMI_AUTO) {
				firingState.targetPusherState = PUSHER_DRIVE_STATE_BRAKE;
				firingState.isFiring = false;

				return; 
		}

			// Firemode is burst. Stop firing and brake motors if all darts have been 
			// fired
			if (firingState.currentFireMode == BURST_FIRE) {
				// All darts fired, stop firing and brake
			  if (firingState.dartsFired >= firingState.dartsToFire) {
			    firingState.targetPusherState = PUSHER_DRIVE_STATE_BRAKE;
			    firingState.dartsFired = 0;
			    firingState.isFiring = false;

			    return;
			  }
			}

			// If code got to here, there are still more darts to be fired. Power on 
			// pusher motor after a slight delay proportional to rate of fire 
			updatePusherMotorTiming();
			Serial.println(firingState.rateOfFire);
			firingState.targetPusherState = PUSHER_DRIVE_STATE_BRAKE;
			firingState.firingTimer.in(
				firingState.pusherMotorOffTime, turnOnPusherMotor);
			

		// Firemode is safety, kill motors
		} else {
			firingState.targetPusherState = PUSHER_DRIVE_STATE_BRAKE;
			firingState.isFiring = false;
		}
	}





	// if (firingState.currentFireMode == SEMI_AUTO 
	// 	|| firingState.currentFireMode == BURST_FIRE) {
 //    handlePusherMotorSemiAutoAndBurst();
 //  } else if (firingState.currentFireMode == FULL_AUTO) {
 //    handlePusherMotorFullAuto();

 //  // Firemode is safety	
 //  } else { 
 //    firingState.targetPusherState = PUSHER_DRIVE_STATE_BRAKE;
 //    firingState.isFiring = false;
 //  }
}

// Update pusher motor off time based on pot reading
void updatePusherMotorTiming() {
	setRateOfFire();

	firingState.pusherMotorOffTime = firingState.rateOfFire * 2;

	// Serial.println(firingState.pusherMotorOffTime);
}

bool turnOnPusherMotor() {
	if (firingState.currentFireMode != SAFETY) {
		// Don't fire if pusher is in full-auto and trigger isn't held
		if (firingState.currentFireMode == FULL_AUTO
			&& !firingState.isTriggerPressed) {
			return true;
		}

		firingState.targetPusherState = PUSHER_DRIVE_STATE_ON;
	}

	return true;
}

void handlePusherMotorSemiAutoAndBurst() {
  // If no more darts to fire, stop solenoid
  if (firingState.dartsFired >= firingState.dartsToFire) {
    firingState.targetPusherState = PUSHER_DRIVE_STATE_BRAKE;
    firingState.dartsFired = 0;
    firingState.isFiring = false;

  // Still more darts to fire, so keep firing pusher
  } else {
  	firingState.targetPusherState = PUSHER_DRIVE_STATE_ON;

  }
}

void handlePusherMotorFullAuto() {
	// Trigger is let go and pusher is retracted, so turn off pusher
  if (!firingState.isTriggerPressed && firingState.isCycCtrlSwPressed) {
    firingState.targetPusherState = PUSHER_DRIVE_STATE_BRAKE;
    firingState.isFiring = false;


  // Trigger still pressed, so keep firing pusher
  } else {
  	firingState.targetPusherState = PUSHER_DRIVE_STATE_ON;

  }
}

void handleSolenoidFiring() {	
	// Right when trigger was pulled, initiate firing sequence
	if (firingState.wasTriggerPulled) {
		// Set solenoid on and off times based on rate of fire
		updateSolenoidTiming();

		// Turn solenoid on, set it to turn off later. Solenoid shouldn't be 
		// turned on in safety
		if (firingState.currentFireMode != SAFETY) {
			firingState.targetPusherState = PUSHER_DRIVE_STATE_ON;
			firingState.firingTimer
				.in(firingState.solenoidOnTime, turnSolenoidOff);

		// Firemode is safety
		} else {
			firingState.targetPusherState = PUSHER_DRIVE_STATE_BRAKE;
			firingState.isFiring = false;
		}
	}

}

// Sets solenoid timing based on rate of fire and duty cycle
void updateSolenoidTiming() {
	setRateOfFire();

	firingState.solenoidOnTime = (100.0 / firingState.rateOfFire) 
		* (firingState.SOLENOID_DUTY_CYCLE / 2.0);

	firingState.solenoidOffTime = firingState.solenoidOnTime 
		/ (firingState.SOLENOID_DUTY_CYCLE/(100.0/2.0));

	// Serial.print("On time "); Serial.println(firingState.solenoidOnTime);
	// Serial.print("Off time "); Serial.println(firingState.solenoidOffTime);
}

void handleSolenoidSemiAutoAndBurst() {
  // If no more darts to fire, stop solenoid
  if (firingState.dartsFired >= firingState.dartsToFire) {
    firingState.targetPusherState = PUSHER_DRIVE_STATE_BRAKE;
    firingState.dartsFired = 0;
    firingState.isFiring = false;

  // Still more darts to fire, so keep firing pusher and continue firing loop
  } else {
  	turnSolenoidOn();
  }
}

void handleSolenoidFullAuto() {
	// Trigger is let go, so turn off solenoid
  if (!firingState.isTriggerPressed) {
    firingState.targetPusherState = PUSHER_DRIVE_STATE_BRAKE;
    firingState.isFiring = false;

  // Trigger still pressed, so keep firing pusher and continue firing loop
  } else {
  	turnSolenoidOn();
  }
}

// Turns solenoid off and continues firing loop. Don't call this if you just 
// want to turn off the solenoid
bool turnSolenoidOff() {
	// Serial.println("Off");
	firingState.targetPusherState = PUSHER_DRIVE_STATE_BRAKE;

	firingState.firingTimer
		.in(firingState.solenoidOffTime, handleSolenoidTuronOn);


	return true;
}

// Called after solenoid turns off and about to turn back on. Ideally, this is 
// executed when plunger in retraced position. Determines whether to continue 
// firing the solenoid or to turn the solenoid off
bool handleSolenoidTuronOn() {
	firingState.dartsFired++;

	// Update timing in case rate of fire changed
	updateSolenoidTiming();

	if (firingState.currentFireMode == SEMI_AUTO 
		|| firingState.currentFireMode == BURST_FIRE) {
    handleSolenoidSemiAutoAndBurst();
  } else if (firingState.currentFireMode == FULL_AUTO) {
    handleSolenoidFullAuto();
  } else {
		firingState.targetPusherState = PUSHER_DRIVE_STATE_BRAKE;
	}

	return true;
}

// Turns solenoid on and continues firing loop. Don't call this if you just 
// want to turn on the solenoid
void turnSolenoidOn() {
	// Serial.println("On");
	firingState.targetPusherState = PUSHER_DRIVE_STATE_ON;

	firingState.firingTimer
 		.in(firingState.solenoidOffTime, turnSolenoidOff);
}

float analogReadingToVoltage() {
	return (analogRead(CURRENT_SENSE_PIN) * ARDUINO_SUPPLY_VOLTAGE)/1024.0;
}

float voltageToCurrent(float voltage) {
	return voltage/SENSE_RESISTANCE;	// Basic Ohm's law
}
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

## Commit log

2019-06-29 add hardware files for v0.1
    [Select-Fire Rapidstrike.brd, Select-Fire Rapidstrike.sch]
2019-06-29 move select-fire RS v0.1 sch and brd files to their respective folders
    [Select-Fire Rapidstrike.brd, Select-Fire Rapidstrike.sch]
2019-09-08 add select-fire rapidstrike v0.2 board and schematics eagle files
    [Select Fire Rapidstrike.sch]
2019-09-08 add board files, images, and schematics for Select-Fire RS v1.0
    [Select Fire Rapidstrike.brd, Select Fire Rapidstrike.sch]
2019-10-24 add hardware files for v1.1 variant
    [Select Fire Rapidstrike.brd, Select Fire Rapidstrike.sch]
2020-04-07 Add wiring diagram for flywheel motors with microswitch
2020-04-18 add hardware files for v1.2
    [Select Fire Rapidstrike.brd, Select Fire Rapidstrike.sch]
2020-04-18 add hardware files for v1.3
    [Select Fire Rapidstrike.brd, Select Fire Rapidstrike.sch]
2020-04-18 refactor and rename a few files
    [Select Fire Rapidstrike.brd, Select Fire Rapidstrike.sch, Select-Fire Rapidstrike.brd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]
2020-07-11 Add wiring diagram for a voltmeter with kill switch

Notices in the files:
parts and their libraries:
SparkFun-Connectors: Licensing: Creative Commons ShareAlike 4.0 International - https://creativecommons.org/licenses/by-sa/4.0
